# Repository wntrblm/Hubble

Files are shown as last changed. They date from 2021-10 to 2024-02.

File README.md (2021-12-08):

# Hubble

Hubble is Winterbloom's re-usable development board for test jigs.

## Repository layout

This repository contains the hardware design files and firmware files for Hubble.

- **firmware/** contains the firmware source code, build scripts, and third-party dependencies. The firmware is written in C using GCC ARM.
- **hardware/** contains the hardware design files for the mainboard, jackboard, panel, and programming board. These are all created using KiCAD.
- **mechanical/** contains various designs for laser-cut and 3d-printed parts used to modify the stock test jig assembly for Hubble.

## License and contributing

Hubble is open-source hardware and software, however, licensing a project like this is a little complicated. Please take a chance to review the [LICENSE](LICENSE.md) file.

We welcome contributions! Please read our [Contributing Guide](CONTRIBUTING.md) and [Code of Conduct](CODE_OF_CONDUCT.md).

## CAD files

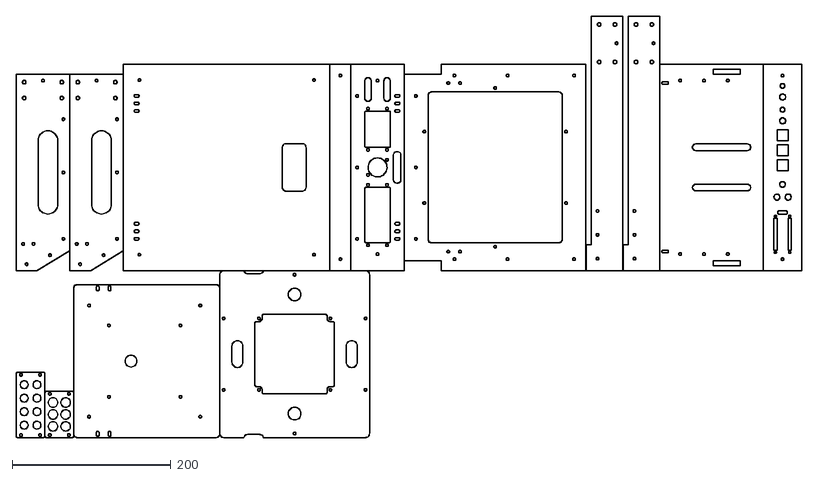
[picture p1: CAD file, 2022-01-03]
mechanical/laser-cuts.dxf
989.4 x 530.3

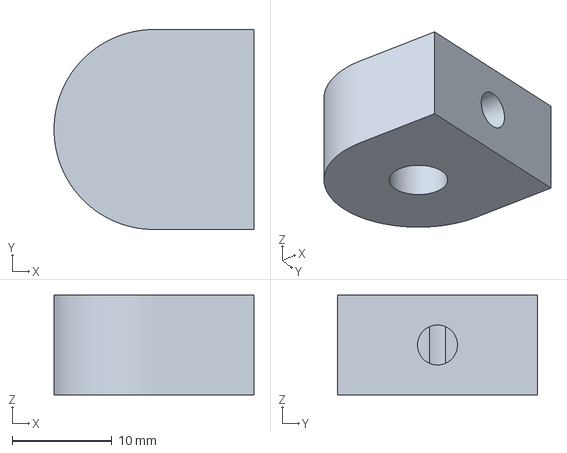
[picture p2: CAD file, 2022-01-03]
mechanical/rail-holder.amf
20.0 x 20.0 x 10.0 mm

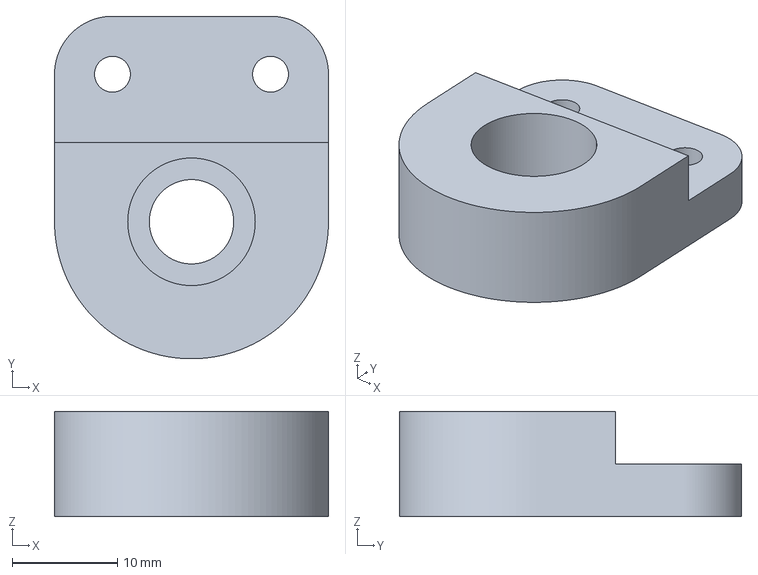
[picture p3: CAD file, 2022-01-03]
mechanical/rail-coupler.amf
26.0 x 32.5 x 10.0 mm

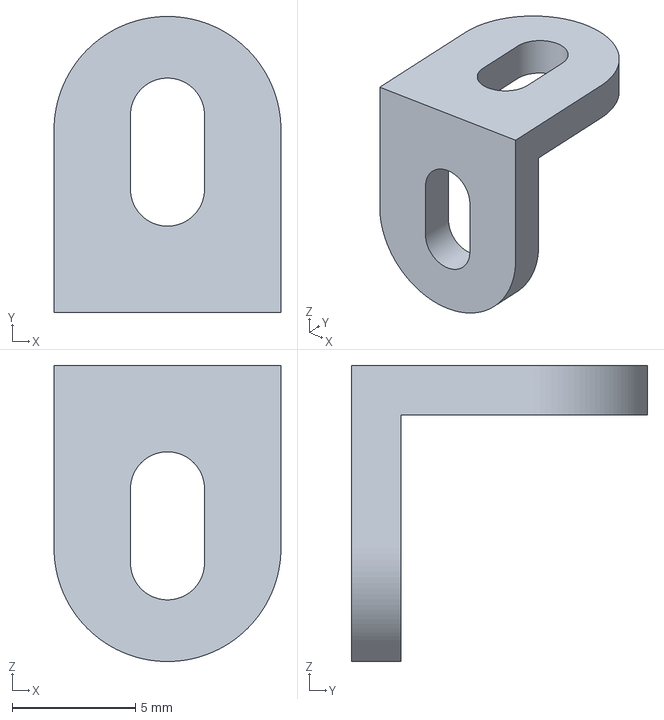
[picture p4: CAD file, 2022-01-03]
mechanical/angle-bracket.amf
9.20 x 12.0 x 12.0 mm

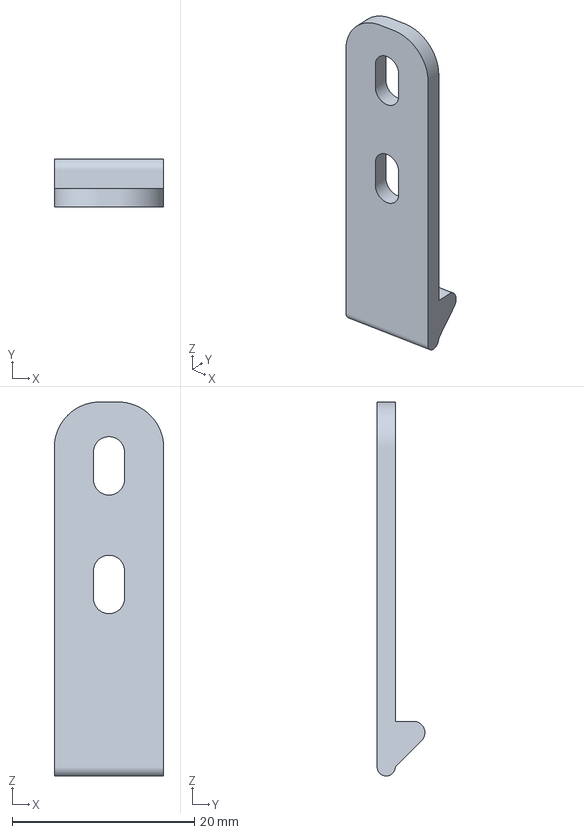
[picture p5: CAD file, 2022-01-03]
mechanical/latch.amf
12.0 x 5.24 x 41.0 mm

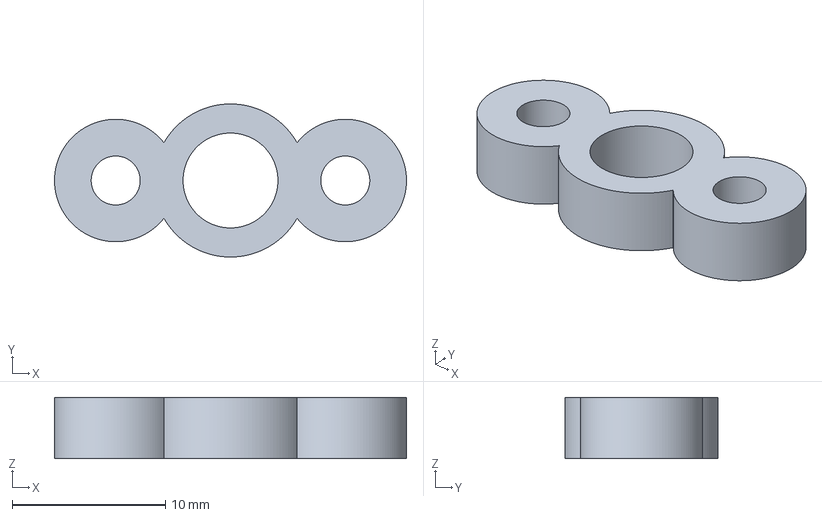
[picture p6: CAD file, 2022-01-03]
mechanical/rail-foot.amf
23.0 x 10.00 x 4.00 mm

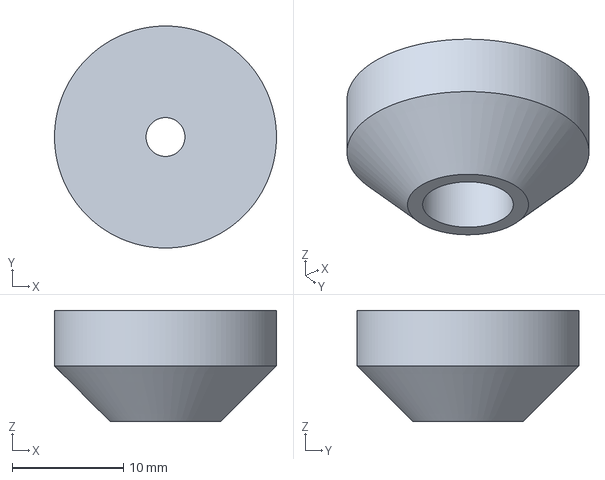
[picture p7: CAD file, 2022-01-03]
mechanical/foot.amf
20.0 x 20.0 x 10.0 mm

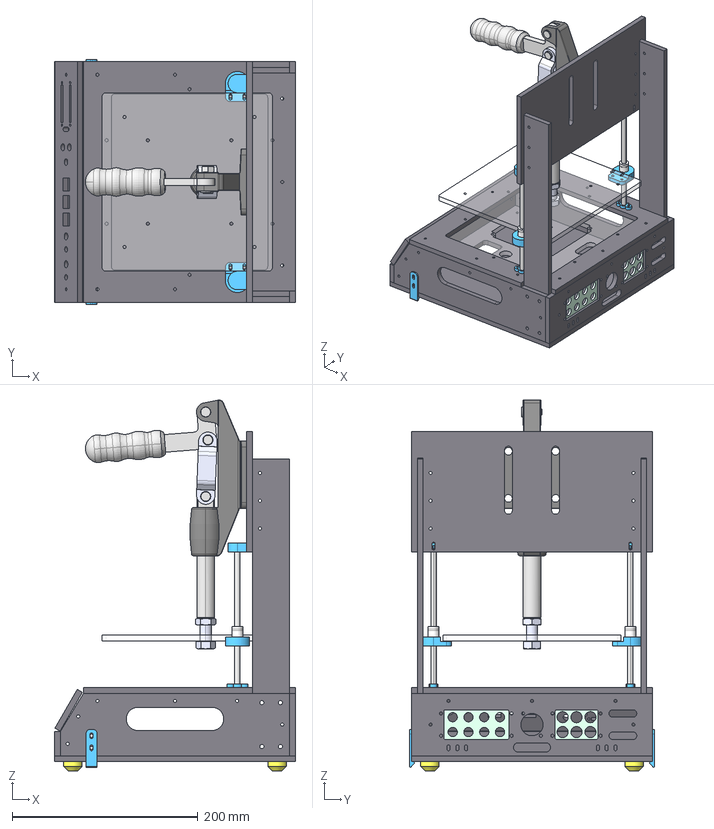
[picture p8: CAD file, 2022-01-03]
mechanical/hubble.FCStd
260.0 x 264.0 x 400.0 mm
6mm x 150mm shaft 5033N123
RailHolder1
RailHolder2
6mm x 150mm shaft 5033N124
RailCoupler1
RailCoupler2
LM6UU1
LM6UU2
RailFoot2
RailFoot1
BoxSide1
BoxSide2
BoxBottom
BoxFront
BoxBack
BoxTop
Arm1
Arm2
ClampPlate
FrontPanel
Foot1
Foot3
Foot4
Foot2
Latch1
Latch2
AngleBracket
Group1^GH-305-HM(²¤ĩ-1
2304HM13-1^GH-305-HM(²¤ĩ-1
Group8^GH-305-HM(²¤ĩ-1
Group5^GH-305-HM(²¤ĩ-1
Group9^GH-305-HM(²¤ĩ-1
LargeIOPlate
SmallIOPlate
PressurePlate
LowerMountingPlate

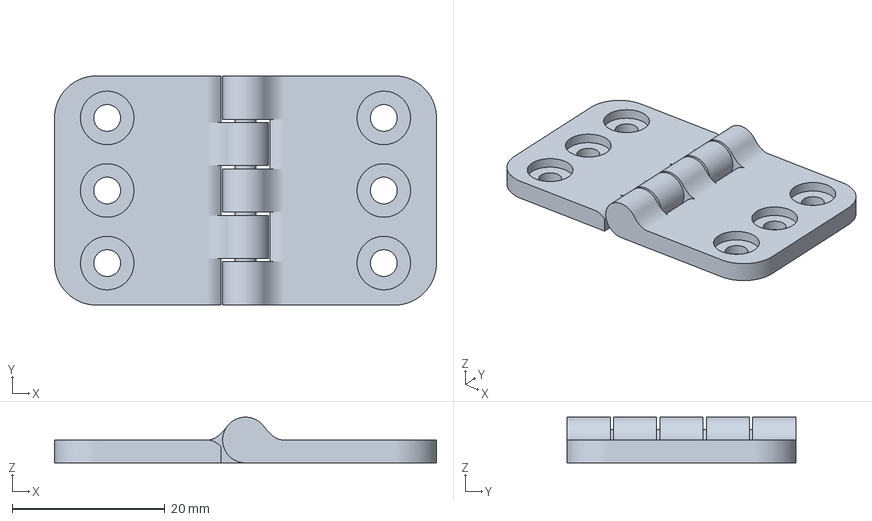
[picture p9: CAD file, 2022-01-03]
mechanical/hinge.3mf
50.0 x 30.0 x 6.00 mm

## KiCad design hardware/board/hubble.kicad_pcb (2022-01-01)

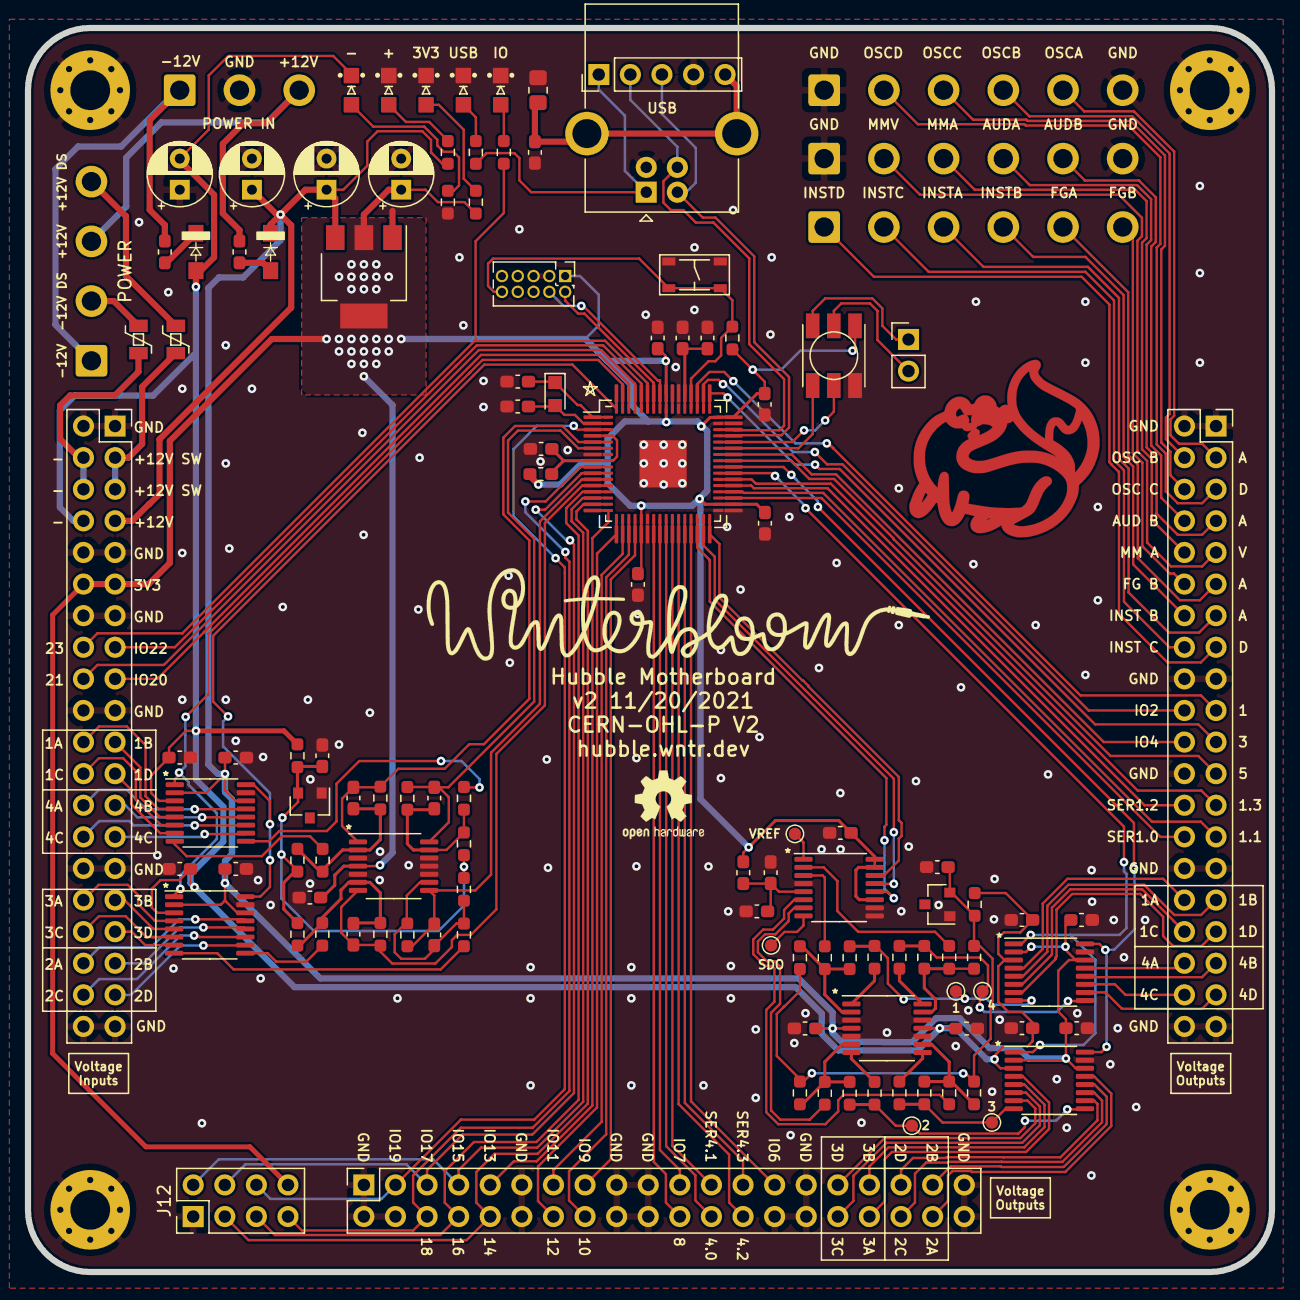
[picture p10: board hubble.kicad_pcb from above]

Board: 2 copper layers, 100.0 x 100.0 mm, 121 parts (0 on the bottom side), 149 nets.

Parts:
C1, C2: 47uF; CP_Radial_D5.0mm_P2.50mm
C3, C4: 10uF; CP_Radial_D5.0mm_P2.50mm
C5: 4.7nF; C_0603_1608Metric_Pad1.08x0.95mm_HandSolder
C6, C9, C11, C12, C13, C14, C15, C16, C17, C19, C20, C25, C26, C27, C28, C29, C30, C31, C32, C33, C34: 0.1uF; C_0603_1608Metric_Pad1.08x0.95mm_HandSolder
C7, C8, C21, C22, C23, C24: 22pF; C_0603_1608Metric_Pad1.08x0.95mm_HandSolder
C10: 4.7uF; C_0603_1608Metric_Pad1.08x0.95mm_HandSolder
C18: 1uF; C_0603_1608Metric_Pad1.08x0.95mm_HandSolder
D1, D2: BARRIER; DIODE_SOD-123_SOD-123F
D3: Dotstar; Dotstar_5050
D4: 3.3; LED_0805_Kingbright_APT2012
D5: +12V; LED_0805_Kingbright_APT2012
D6: -12V; LED_0805_Kingbright_APT2012
D7: ACT; LED_0805_Kingbright_APT2012
D8: VBUS; LED_0805_Kingbright_APT2012
F1, F2: 1A Polyfuse; Littelfuse_0805L
FB1, FB2: 1A; L_0603_1608Metric_Pad1.05x0.95mm_HandSolder
FB3, FB4: 300mA; L_0603_1608Metric_Pad1.05x0.95mm_HandSolder
H1, H2, H3, H4: M3; MountingHole_3.2mm_M3_Pad_Via
J1: POWER; SolderWire-0.75sqmm_1x03_P4.8mm_D1.25mm_OD2.3mm
J2: SWD; PinHeader_2x05_P1.27mm_Vertical
J3: USB B; USB_B_OST_USB-B1HSxx_Horizontal
J4, J8, J9: EXT; SolderWire-0.75sqmm_1x06_P4.8mm_D1.25mm_OD2.3mm
J5: Left; PinSocket_2x20_P2.54mm_Vertical
J6: Right; PinSocket_2x20_P2.54mm_Vertical
J7: Bottom; PinSocket_2x20_P2.54mm_Vertical
J10: Dotstars; PinHeader_1x02_P2.54mm_Vertical
J11: USB; PinHeader_1x05_P2.54mm_Vertical
J12: FRONT; PinHeader_2x04_P2.54mm_Vertical
R1, R2, R3, R4, R6, R15, R16, R17, R18, R35: 10k; R_0603_1608Metric_Pad0.98x0.95mm_HandSolder
R5: 1M; R_0805_2012Metric_Pad1.20x1.40mm_HandSolder
R7, R9, R11, R13: 1.54k; R_0603_1608Metric_Pad0.98x0.95mm_HandSolder
R8, R10, R12, R14: 12.4k; R_0603_1608Metric_Pad0.98x0.95mm_HandSolder
R19, R20, R21, R22, R37: 1k; R_0603_1608Metric_Pad0.98x0.95mm_HandSolder
R23, R25, R27, R29: 100k; R_0603_1608Metric_Pad0.98x0.95mm_HandSolder
R24, R26, R28, R30: 121k; R_0603_1608Metric_Pad0.98x0.95mm_HandSolder
R31, R32, R33, R34: 18.7k; R_0603_1608Metric_Pad0.98x0.95mm_HandSolder
R36: 270; R_0603_1608Metric_Pad0.98x0.95mm_HandSolder
SW1: POWER; SolderWire-0.75sqmm_1x04_P4.8mm_D1.25mm_OD2.3mm
SW2: Reset; Tactile_Switch_4.2mm
TP1: SDO; TestPoint_Pad_D1.0mm
TP2: VREF; TestPoint_Pad_D1.0mm
TP3: 1; TestPoint_Pad_D1.0mm
TP4: 2; TestPoint_Pad_D1.0mm
TP5: 3; TestPoint_Pad_D1.0mm
TP6: 4; TestPoint_Pad_D1.0mm
U1: LD1117-3.3; SOT-223-3_TabPin2
U2, U3: LM4040-10; SOT-23
U4, U7, U8, U9: MUX509; TSSOP-16_4.4x5mm_P0.65mm
U5: ATSAMD51J20A-M; QFN+QFP-64-SAMD51
U6: AD5689R?RUZ; TSSOP-16_4.4x5mm_P0.65mm
U10: OPA4197; TSSOP-14_4.4x5mm_P0.65mm
U11: MCP6004; TSSOP-14_4.4x5mm_P0.65mm
Y1: 32.768 kHz; Crystal_SMD_2012-2Pin_2.0x1.2mm_HandSoldering

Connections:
+3V3: C4.1, C11.1, C12.1, C13.1, C14.1, C16.1, C20.1, D3.4, FB3.2, FB4.2, J2.1, J5.11, J5.12, J12.8, R1.1, R4.2, U1.2, U5.21, U5.34, U5.48, U5.56, U6.11, U6.15, U6.16, U11.4
+12V: C1.1, C3.1, C29.1, C30.1, C31.1, C32.1, C34.1, D2.1, J5.7, R2.1, U1.3, U4.2, U4.14, U7.2, U7.14, U8.2, U8.14, U9.2, U9.14, U10.4
+12VDOWNSTREAM: F1.1, J5.3, J5.5
+12VRAW: FB1.1, J1.3, SW1.3
-12V: C2.2, C25.1, C26.1, C27.1, C28.1, C33.2, D1.2, D6.1, J5.8, R36.1, R37.1, U4.3, U7.3, U8.3, U9.3, U10.11
-12VDOWNSTREAM: F2.2, J5.4, J5.6
-12VRAW: FB2.1, J1.1, SW1.1
/ADC_1A: J5.22, U7.4
/ADC_1B: J5.21, U7.5
/ADC_1C: J5.24, U7.6
/ADC_1D: J5.23, U7.7
/ADC_2A: J5.36, U8.13
/ADC_2B: J5.35, U8.12
/ADC_2C: J5.38, U8.11
/ADC_2D: J5.37, U8.10
/ADC_3A: J5.32, U8.4
/ADC_3B: J5.31, U8.5
/ADC_3C: J5.34, U8.6
/ADC_3D: J5.33, U8.7
/ADC_4A: J5.26, U7.13
/ADC_4B: J5.25, U7.12
/ADC_4C: J5.28, U7.11
/ADC_4D: J5.27, U7.10
/AnalogInBuffers/-10v_ADC: C19.2, R24.2, R26.2, R28.2, R30.2, R37.2, U3.2
/AnalogOutBuffers/-10v_DAC: C15.2, R8.2, R10.2, R12.2, R14.2, R36.2, U2.2
/DAC/DAC_1: R7.2, U6.3
/DAC/DAC_2: R9.2, U6.7
/DAC/DAC_3: R11.2, U6.6
/DAC/DAC_4: R13.2, U6.2
/DAC/SPI_COPI: U5.32, U6.14
/DAC/VDD_DAC: C17.1, C18.1, FB4.1, U6.5
/DAC_1A: J6.32, U9.4
/DAC_1B: J6.31, U9.5
/DAC_1C: J6.34, U9.6
/DAC_1D: J6.33, U9.7
/DAC_2A: J7.38, U4.13
/DAC_2B: J7.37, U4.12
/DAC_2C: J7.36, U4.11
/DAC_2D: J7.35, U4.10
/DAC_3A: J7.34, U4.4
/DAC_3B: J7.33, U4.5
/DAC_3C: J7.32, U4.6
/DAC_3D: J7.31, U4.7
/DAC_4A: J6.36, U9.13
/DAC_4B: J6.35, U9.12
/DAC_4C: J6.38, U9.11
/DAC_4D: J6.37, U9.10
/EXT_AUDIO_A: J4.4, J6.7
/EXT_AUDIO_B: J4.5, J6.8
/EXT_FG_A: J6.11, J9.5
/EXT_FG_B: J6.12, J9.6
/EXT_INST_A: J6.13, J9.3
/EXT_INST_B: J6.14, J9.4
/EXT_INST_C: J6.16, J9.2
/EXT_INST_D: J6.15, J9.1
/EXT_MM_A: J4.3, J6.10
/EXT_MM_V: J4.2, J6.9
/EXT_OSC_A: J6.3, J8.5
/EXT_OSC_B: J6.4, J8.4
/EXT_OSC_C: J6.6, J8.3
/EXT_OSC_D: J6.5, J8.2
/IO1: J6.19, U5.51
/IO2: J6.20, U5.50
/IO3: J6.21, U5.49
/IO4: J6.22, U5.42
/IO5: J6.23, U5.41
/IO6: J7.27, U5.29
/IO7: J7.21, U5.24
/IO8: J7.22, U5.23
/IO9: J7.15, U5.20
/IO10: J7.16, U5.19
/IO11: J7.13, U5.18
/IO12: J7.14, U5.17
/IO13: J7.9, U5.16
/IO14: J7.10, J12.3, U5.15
/IO15: J7.7, J12.2, U5.14
/IO16: J7.8, J12.5, U5.13
/IO17: J7.5, J12.4, U5.10
/IO18: J7.6, J12.7, U5.9
/IO19: J7.3, J12.6, U5.3
/IO20: J5.17, U5.62
/IO21: J5.18, U5.61
/IO22: J5.15, U5.60
/IO23: J5.16, R6.1, U5.59
/MCU/A1: C21.2, R31.1, U5.5, U11.1
/MCU/A2: C22.2, R32.1, U5.12, U11.7
/MCU/A3: C23.2, R33.1, U5.11, U11.8
/MCU/A4: C24.2, R34.1, U5.6, U11.14
/MCU/ADC0.AIN1+ANAREF.VREF0: C6.1, FB3.1, U5.4, U5.8
/MCU/D+: J3.3, J11.2, U5.46
/MCU/D-: J3.2, J11.3, U5.45
/MCU/DAC_CS: U5.31, U6.13
/MCU/DOTSTAR_CI: D3.2, U5.44
/MCU/DOTSTAR_DI: D3.1, U5.43
/MCU/RESET: J2.10, R4.1, SW2.1, U5.52
/MCU/SPI_SCK: U5.30, U6.12
/MCU/SWCLK: J2.4, U5.57
/MCU/SWDIO: J2.2, U5.58
/MCU/VBUS: J3.1, J11.1, R35.1
/MCU/VDDCORE: C9.1, C10.1, U5.53
/MCU/XIN: C7.2, U5.1, Y1.1
/MCU/XOUT: C8.2, U5.2, Y1.2
/Switching/ADC_1: R23.2, U7.8
/Switching/ADC_2: R25.2, U8.9
/Switching/ADC_3: R27.2, U8.8
/Switching/ADC_4: R29.2, U7.9
/Switching/ADC_A0: U5.63, U7.1, U8.1
/Switching/ADC_A1: U5.64, U7.16, U8.16
/Switching/DAC_1: R15.1, R19.1, TP3.1, U9.8
/Switching/DAC_2: R16.1, R20.1, TP4.1, U4.9
/Switching/DAC_3: R17.1, R21.1, TP5.1, U4.8
/Switching/DAC_4: R18.1, R22.1, TP6.1, U9.9
/Switching/DAC_A0: U4.1, U5.39, U9.1
/Switching/DAC_A1: U4.16, U5.40, U9.16
GND: C1.2, C2.1, C3.2, C4.2, C5.2, C6.2, C7.1, C8.1, C9.2, C10.2, C11.2, C12.2, C13.2, C14.2, C15.1, C16.2, C17.2, C18.2, C19.1, C20.2, C25.2, C26.2, C27.2, C28.2, C29.2, C30.2, C31.2, C32.2, C33.1, C34.2, D3.3, D4.1, D5.1, D7.1, D8.1, H1.1, H2.1, H3.1, H4.1, J1.2, J2.3, J2.5, J2.9, J3.4, J4.1, J4.6, J5.1, J5.2, J5.9, J5.10, J5.13, J5.14, J5.19, J5.20, J5.29, J5.30, J5.39, J5.40, J6.1, J6.2, J6.17, J6.18, J6.24, J6.29, J6.30, J6.39, J6.40, J7.1, J7.2, J7.4, J7.11, J7.12, J7.17, J7.18, J7.19, J7.20, J7.28, J7.29, J7.30, J7.39, J7.40, J8.1, J8.6, J11.4, J12.1, R3.1, R5.2, SW2.2, U1.1, U2.1, U3.1, U4.15, U5.7, U5.22, U5.33, U5.47, U5.54, U5.65, U6.4, U6.9, U6.10, U7.15, U8.15, U9.15, U10.3, U10.5, U10.10, U10.12, U11.3, U11.5, U11.10, U11.11, U11.12
unnamed: C5.1, J3.5, J11.5, R5.1
unnamed: C21.1, R23.1, R24.1, R31.2, U11.2
unnamed: C22.1, R25.1, R26.1, R32.2, U11.6
unnamed: C23.1, R27.1, R28.1, R33.2, U11.9
unnamed: C24.1, R29.1, R30.1, R34.2, U11.13
unnamed: D1.1, FB2.2
unnamed: D2.2, FB1.2
unnamed: D3.5, J10.2
unnamed: D3.6, J10.1
unnamed: D4.2, R1.2
unnamed: D5.2, R2.2
unnamed: D6.2, R3.2
unnamed: D7.2, R6.2
unnamed: D8.2, R35.2
unnamed: F1.2, SW1.4
unnamed: F2.1, SW1.2
unnamed: R9.1, R10.1, R16.2, U10.6
unnamed: R11.1, R12.1, R17.2, U10.9
unnamed: R13.1, R14.1, R18.2, U10.13
unnamed: R7.1, R8.1, R15.2, U10.2
unnamed: R19.2, U10.1
unnamed: R20.2, U10.7
unnamed: R21.2, U10.8
unnamed: R22.2, U10.14
unnamed: TP1.1, U6.8
unnamed: TP2.1, U6.1
SERIAL1.0: J6.28, U5.35
SERIAL1.1: J6.27, U5.36
SERIAL1.2: J6.26, U5.37
SERIAL1.3: J6.25, U5.38
SERIAL4.0: J7.24, U5.25
SERIAL4.1: J7.23, U5.26
SERIAL4.2: J7.26, U5.27
SERIAL4.3: J7.25, U5.28

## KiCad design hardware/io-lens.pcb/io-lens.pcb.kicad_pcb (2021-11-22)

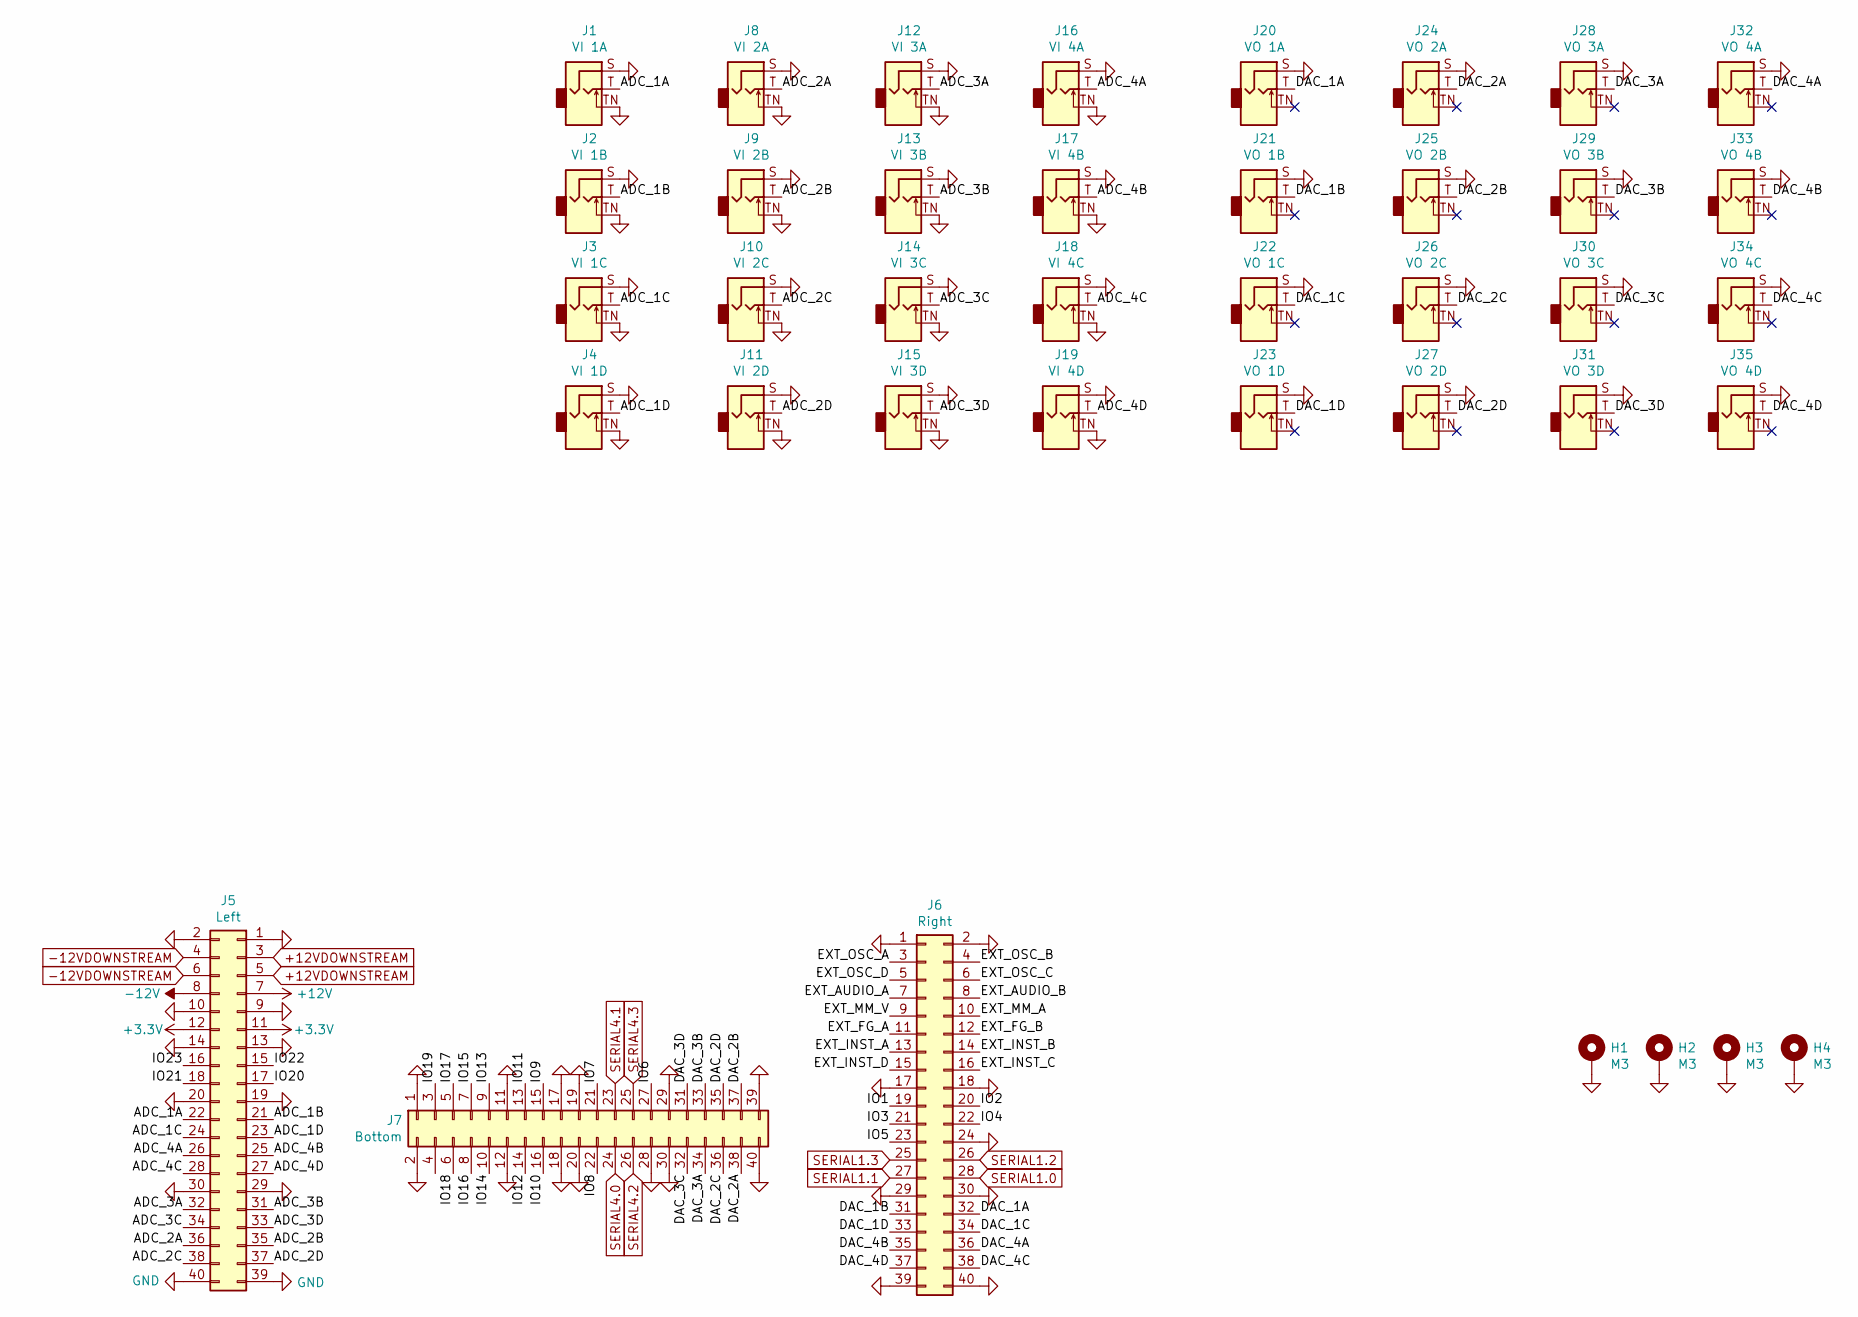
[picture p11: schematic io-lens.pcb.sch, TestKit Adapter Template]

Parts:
H1, H2, H3, H4: M3; MountingHole_3.2mm_M3_Pad_Via
J1: VI 1A; WQP-WQP518MA; mpn WQP-WQP518MA
J2: VI 1B; WQP-WQP518MA; mpn WQP-WQP518MA
J3: VI 1C; WQP-WQP518MA; mpn WQP-WQP518MA
J4: VI 1D; WQP-WQP518MA; mpn WQP-WQP518MA
J5: Left; PinSocket_2x20_P2.54mm_Vertical
J6: Right; PinSocket_2x20_P2.54mm_Vertical
J7: Bottom; PinSocket_2x20_P2.54mm_Vertical
J8: VI 2A; WQP-WQP518MA; mpn WQP-WQP518MA
J9: VI 2B; WQP-WQP518MA; mpn WQP-WQP518MA
J10: VI 2C; WQP-WQP518MA; mpn WQP-WQP518MA
J11: VI 2D; WQP-WQP518MA; mpn WQP-WQP518MA
J12: VI 3A; WQP-WQP518MA; mpn WQP-WQP518MA
J13: VI 3B; WQP-WQP518MA; mpn WQP-WQP518MA
J14: VI 3C; WQP-WQP518MA; mpn WQP-WQP518MA
J15: VI 3D; WQP-WQP518MA; mpn WQP-WQP518MA
J16: VI 4A; WQP-WQP518MA; mpn WQP-WQP518MA
J17: VI 4B; WQP-WQP518MA; mpn WQP-WQP518MA
J18: VI 4C; WQP-WQP518MA; mpn WQP-WQP518MA
J19: VI 4D; WQP-WQP518MA; mpn WQP-WQP518MA
J20: VO 1A; WQP-WQP518MA; mpn WQP-WQP518MA
J21: VO 1B; WQP-WQP518MA; mpn WQP-WQP518MA
J22: VO 1C; WQP-WQP518MA; mpn WQP-WQP518MA
J23: VO 1D; WQP-WQP518MA; mpn WQP-WQP518MA
J24: VO 2A; WQP-WQP518MA; mpn WQP-WQP518MA
J25: VO 2B; WQP-WQP518MA; mpn WQP-WQP518MA
J26: VO 2C; WQP-WQP518MA; mpn WQP-WQP518MA
J27: VO 2D; WQP-WQP518MA; mpn WQP-WQP518MA
J28: VO 3A; WQP-WQP518MA; mpn WQP-WQP518MA
J29: VO 3B; WQP-WQP518MA; mpn WQP-WQP518MA
J30: VO 3C; WQP-WQP518MA; mpn WQP-WQP518MA
J31: VO 3D; WQP-WQP518MA; mpn WQP-WQP518MA
J32: VO 4A; WQP-WQP518MA; mpn WQP-WQP518MA
J33: VO 4B; WQP-WQP518MA; mpn WQP-WQP518MA
J34: VO 4C; WQP-WQP518MA; mpn WQP-WQP518MA
J35: VO 4D; WQP-WQP518MA; mpn WQP-WQP518MA

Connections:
+3V3: J5.11, J5.12
+12V: J5.7
+12VDOWNSTREAM: J5.3, J5.5
-12V: J5.8
-12VDOWNSTREAM: J5.4, J5.6
/ADC_1A: J1.T (Tip), J5.22
/ADC_1B: J2.T (Tip), J5.21
/ADC_1C: J3.T (Tip), J5.24
/ADC_1D: J4.T (Tip), J5.23
/ADC_2A: J5.36, J8.T (Tip)
/ADC_2B: J5.35, J9.T (Tip)
/ADC_2C: J5.38, J10.T (Tip)
/ADC_2D: J5.37, J11.T (Tip)
/ADC_3A: J5.32, J12.T (Tip)
/ADC_3B: J5.31, J13.T (Tip)
/ADC_3C: J5.34, J14.T (Tip)
/ADC_3D: J5.33, J15.T (Tip)
/ADC_4A: J5.26, J16.T (Tip)
/ADC_4B: J5.25, J17.T (Tip)
/ADC_4C: J5.28, J18.T (Tip)
/ADC_4D: J5.27, J19.T (Tip)
/DAC_1A: J6.32, J20.T (Tip)
/DAC_1B: J6.31, J21.T (Tip)
/DAC_1C: J6.34, J22.T (Tip)
/DAC_1D: J6.33, J23.T (Tip)
/DAC_2A: J7.38, J24.T (Tip)
/DAC_2B: J7.37, J25.T (Tip)
/DAC_2C: J7.36, J26.T (Tip)
/DAC_2D: J7.35, J27.T (Tip)
/DAC_3A: J7.34, J28.T (Tip)
/DAC_3B: J7.33, J29.T (Tip)
/DAC_3C: J7.32, J30.T (Tip)
/DAC_3D: J7.31, J31.T (Tip)
/DAC_4A: J6.36, J32.T (Tip)
/DAC_4B: J6.35, J33.T (Tip)
/DAC_4C: J6.38, J34.T (Tip)
/DAC_4D: J6.37, J35.T (Tip)
/EXT_AUDIO_A: J6.7
/EXT_AUDIO_B: J6.8
/EXT_FG_A: J6.11
/EXT_FG_B: J6.12
/EXT_INST_A: J6.13
/EXT_INST_B: J6.14
/EXT_INST_C: J6.16
/EXT_INST_D: J6.15
/EXT_MM_A: J6.10
/EXT_MM_V: J6.9
/EXT_OSC_A: J6.3
/EXT_OSC_B: J6.4
/EXT_OSC_C: J6.6
/EXT_OSC_D: J6.5
/IO1: J6.19
/IO2: J6.20
/IO3: J6.21
/IO4: J6.22
/IO5: J6.23
/IO6: J7.27
/IO7: J7.21
/IO8: J7.22
/IO9: J7.15
/IO10: J7.16
/IO11: J7.13
/IO12: J7.14
/IO13: J7.9
/IO14: J7.10
/IO15: J7.7
/IO16: J7.8
/IO17: J7.5
/IO18: J7.6
/IO19: J7.3
/IO20: J5.17
/IO21: J5.18
/IO22: J5.15
/IO23: J5.16
GND: H1.1, H2.1, H3.1, H4.1, J1.S (Sleeve), J1.TN (Tip_normalize), J2.S (Sleeve), J2.TN (Tip_normalize), J3.S (Sleeve), J3.TN (Tip_normalize), J4.S (Sleeve), J4.TN (Tip_normalize), J5.1, J5.2, J5.9, J5.10, J5.13, J5.14, J5.19, J5.20, J5.29, J5.30, J5.39, J5.40, J6.1, J6.2, J6.17, J6.18, J6.24, J6.29, J6.30, J6.39, J6.40, J7.1, J7.2, J7.11, J7.12, J7.17, J7.18, J7.19, J7.20, J7.28, J7.29, J7.30, J7.39, J7.40, J8.S (Sleeve), J8.TN (Tip_normalize), J9.S (Sleeve), J9.TN (Tip_normalize), J10.S (Sleeve), J10.TN (Tip_normalize), J11.S (Sleeve), J11.TN (Tip_normalize), J12.S (Sleeve), J12.TN (Tip_normalize), J13.S (Sleeve), J13.TN (Tip_normalize), J14.S (Sleeve), J14.TN (Tip_normalize), J15.S (Sleeve), J15.TN (Tip_normalize), J16.S (Sleeve), J16.TN (Tip_normalize), J17.S (Sleeve), J17.TN (Tip_normalize), J18.S (Sleeve), J18.TN (Tip_normalize), J19.S (Sleeve), J19.TN (Tip_normalize), J20.S (Sleeve), J21.S (Sleeve), J22.S (Sleeve), J23.S (Sleeve), J24.S (Sleeve), J25.S (Sleeve), J26.S (Sleeve), J27.S (Sleeve), J28.S (Sleeve), J29.S (Sleeve), J30.S (Sleeve), J31.S (Sleeve), J32.S (Sleeve), J33.S (Sleeve), J34.S (Sleeve), J35.S (Sleeve)
SERIAL1.0: J6.28
SERIAL1.1: J6.27
SERIAL1.2: J6.26
SERIAL1.3: J6.25
SERIAL4.0: J7.24
SERIAL4.1: J7.23
SERIAL4.2: J7.26
SERIAL4.3: J7.25

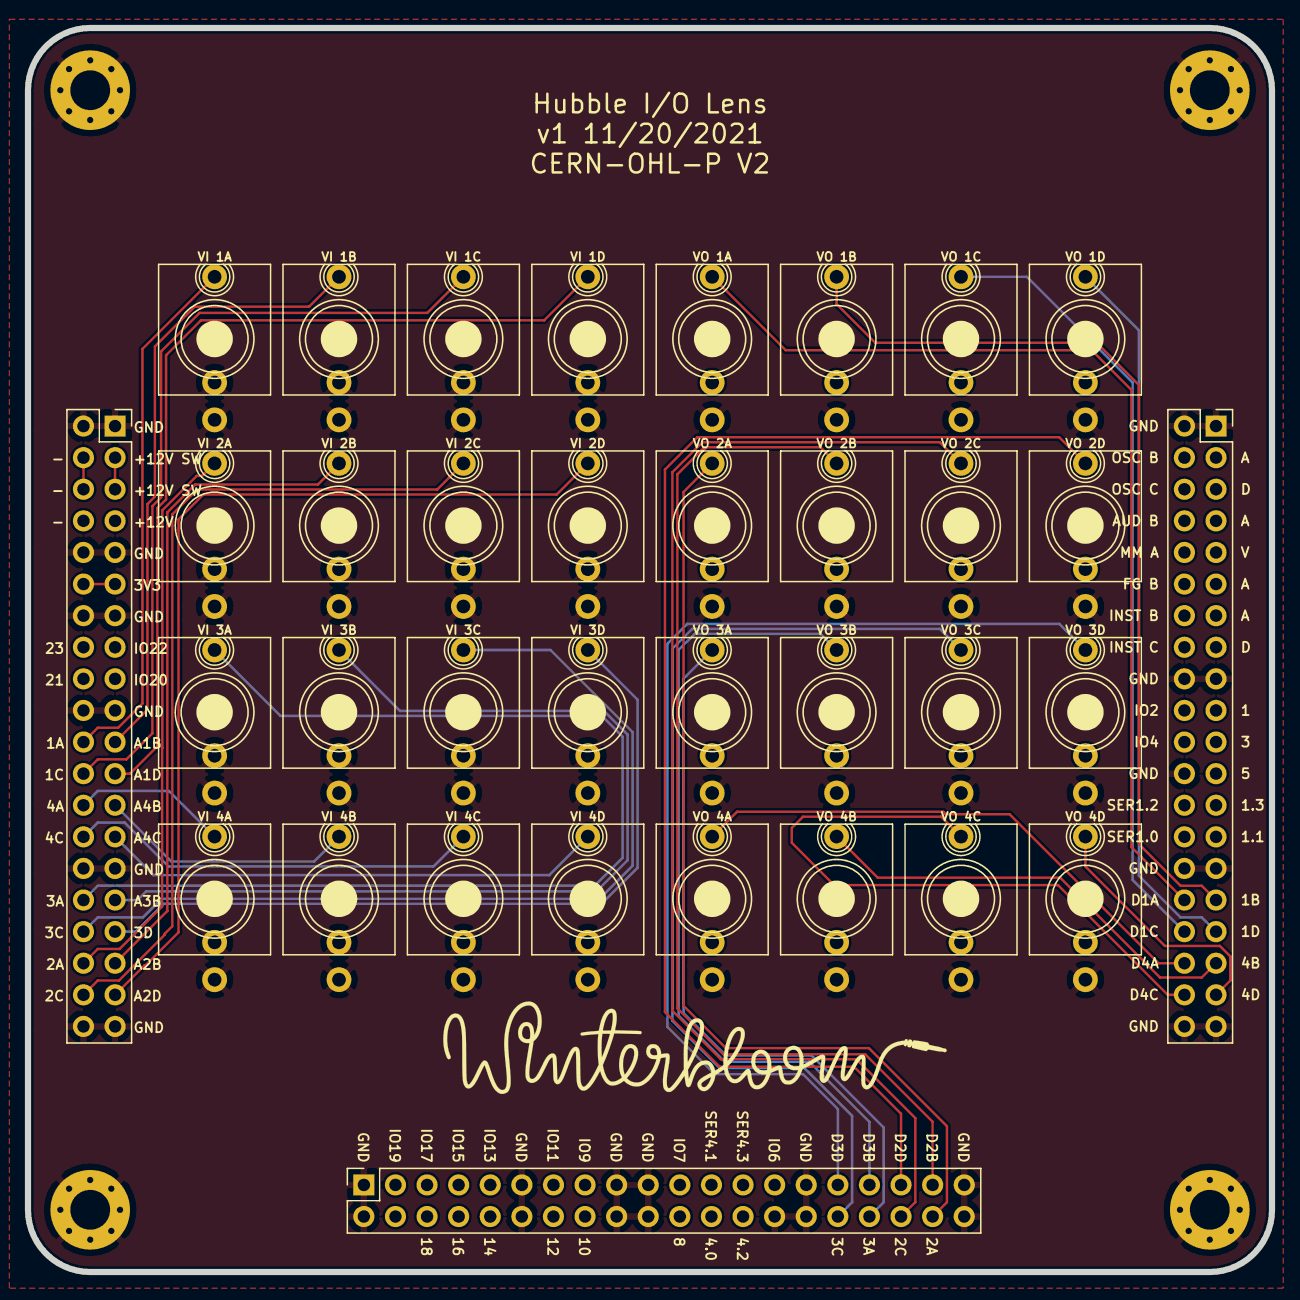
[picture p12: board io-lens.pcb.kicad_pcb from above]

Board: 2 copper layers, 100.0 x 100.0 mm, 39 parts (0 on the bottom side), 36 nets.

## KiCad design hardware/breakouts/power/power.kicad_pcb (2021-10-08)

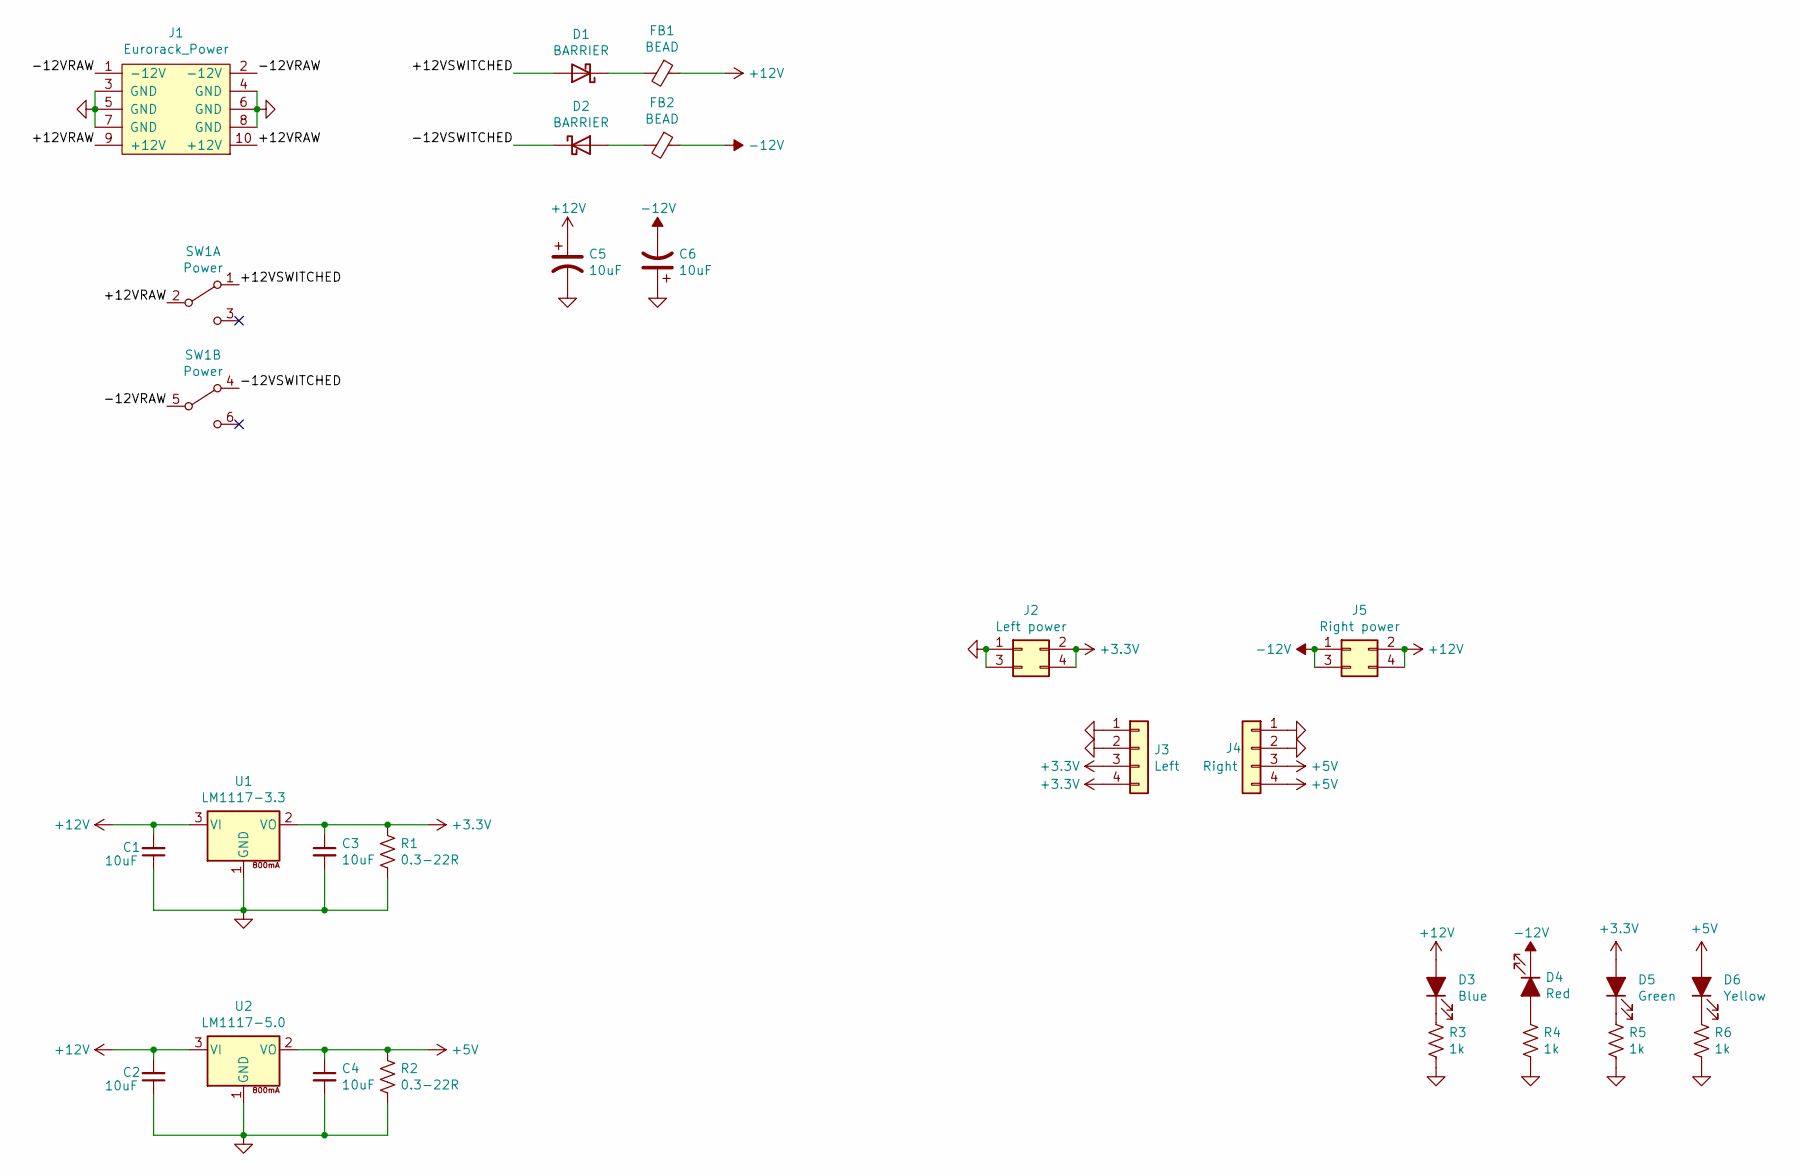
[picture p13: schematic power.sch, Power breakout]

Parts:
C1, C2, C3, C4: 10uF; C_0805_2012Metric_Pad1.18x1.45mm_HandSolder
C5, C6: 10uF; CP_Radial_D5.0mm_P2.50mm
D1, D2: BARRIER; D_SOD-123
D3: Blue; LED_D3.0mm
D4: Red; LED_D3.0mm
D5: Green; LED_D3.0mm
D6: Yellow; LED_D3.0mm
FB1, FB2: BEAD; L_0603_1608Metric_Pad1.05x0.95mm_HandSolder
J1: Eurorack_Power; mpn 302-S101
J2: Left power; PinHeader_2x02_P2.54mm_Vertical
J3: Left; PinHeader_1x04_P2.54mm_Vertical
J4: Right; PinHeader_1x04_P2.54mm_Vertical
J5: Right power; PinHeader_2x02_P2.54mm_Vertical
R1, R2: 0.3-22R; R_0805_2012Metric
R3, R4, R5, R6: 1k; R_0603_1608Metric_Pad0.98x0.95mm_HandSolder
SW1: Power; Switch_DPDT_Thonk_DW4_2.54mm_pitch_5.08mm_spacing
U1: LM1117-3.3; SOT-223-3_TabPin2; mpn LM1117IMP-3.3
U2: LM1117-5.0; SOT-223-3_TabPin2; mpn LM1117IMP-3.3

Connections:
+3V3: C3.1, D5.2 (A), J2.2, J2.4, J3.3, J3.4, R1.1, U1.2 (VO)
+5V: C4.1, D6.2 (A), J4.3, J4.4, R2.1, U2.2 (VO)
+12V: C1.2, C2.2, C5.1, D3.2 (A), FB1.1, J5.2, J5.4, U1.3 (VI), U2.3 (VI)
-12V: C6.2, D4.1 (K), FB2.1, J5.1, J5.3
/+12VRAW: J1.9 (+12V), J1.10 (+12V), SW1.2 (B)
/+12VSWITCHED: D1.2 (A), SW1.1 (A)
/-12VRAW: J1.1 (-12V), J1.2 (-12V), SW1.5 (B)
/-12VSWITCHED: D2.1 (K), SW1.4 (A)
GND: C1.1, C2.1, C3.2, C4.2, C5.2, C6.1, J1.3 (GND), J1.4 (GND), J1.5 (GND), J1.6 (GND), J1.7 (GND), J1.8 (GND), J2.1, J2.3, J3.1, J3.2, J4.1, J4.2, R1.2, R2.2, R3.2, R4.2, R5.2, R6.2, U1.1 (GND), U2.1 (GND)
unnamed: D1.1 (K), FB1.2
unnamed: D2.2 (A), FB2.2
unnamed: D3.1 (K), R3.1
unnamed: D4.2 (A), R4.1
unnamed: D5.1 (K), R5.1
unnamed: D6.1 (K), R6.1

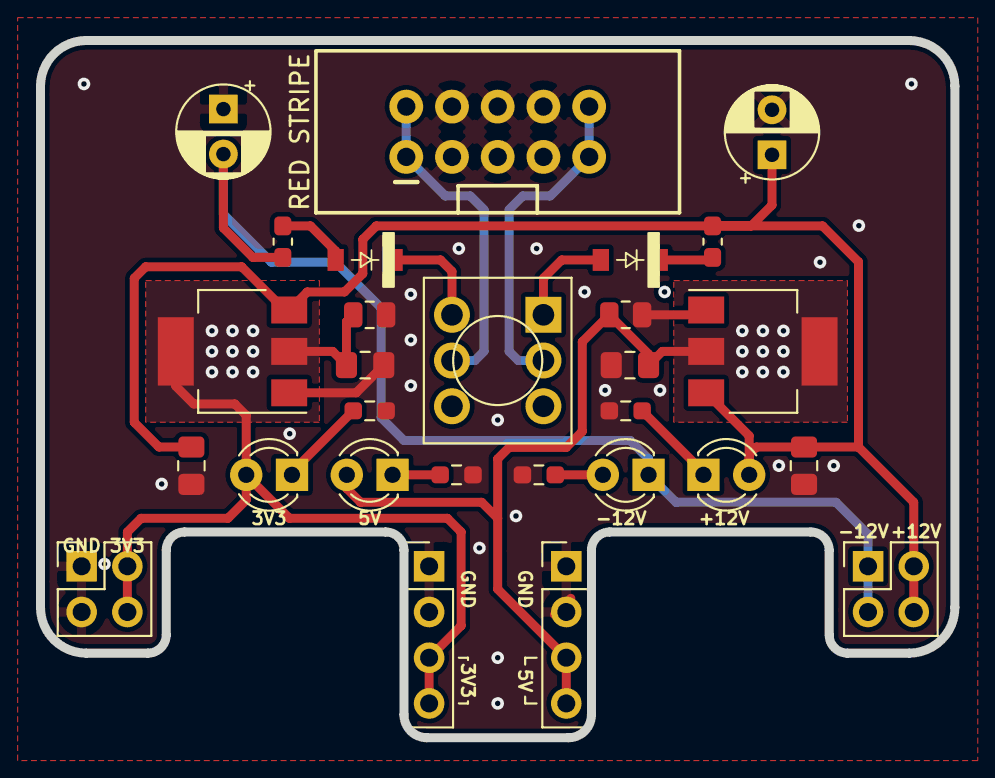
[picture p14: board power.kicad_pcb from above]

Board: 2 copper layers, 50.8 x 38.7 mm, 28 parts (0 on the bottom side), 15 nets.

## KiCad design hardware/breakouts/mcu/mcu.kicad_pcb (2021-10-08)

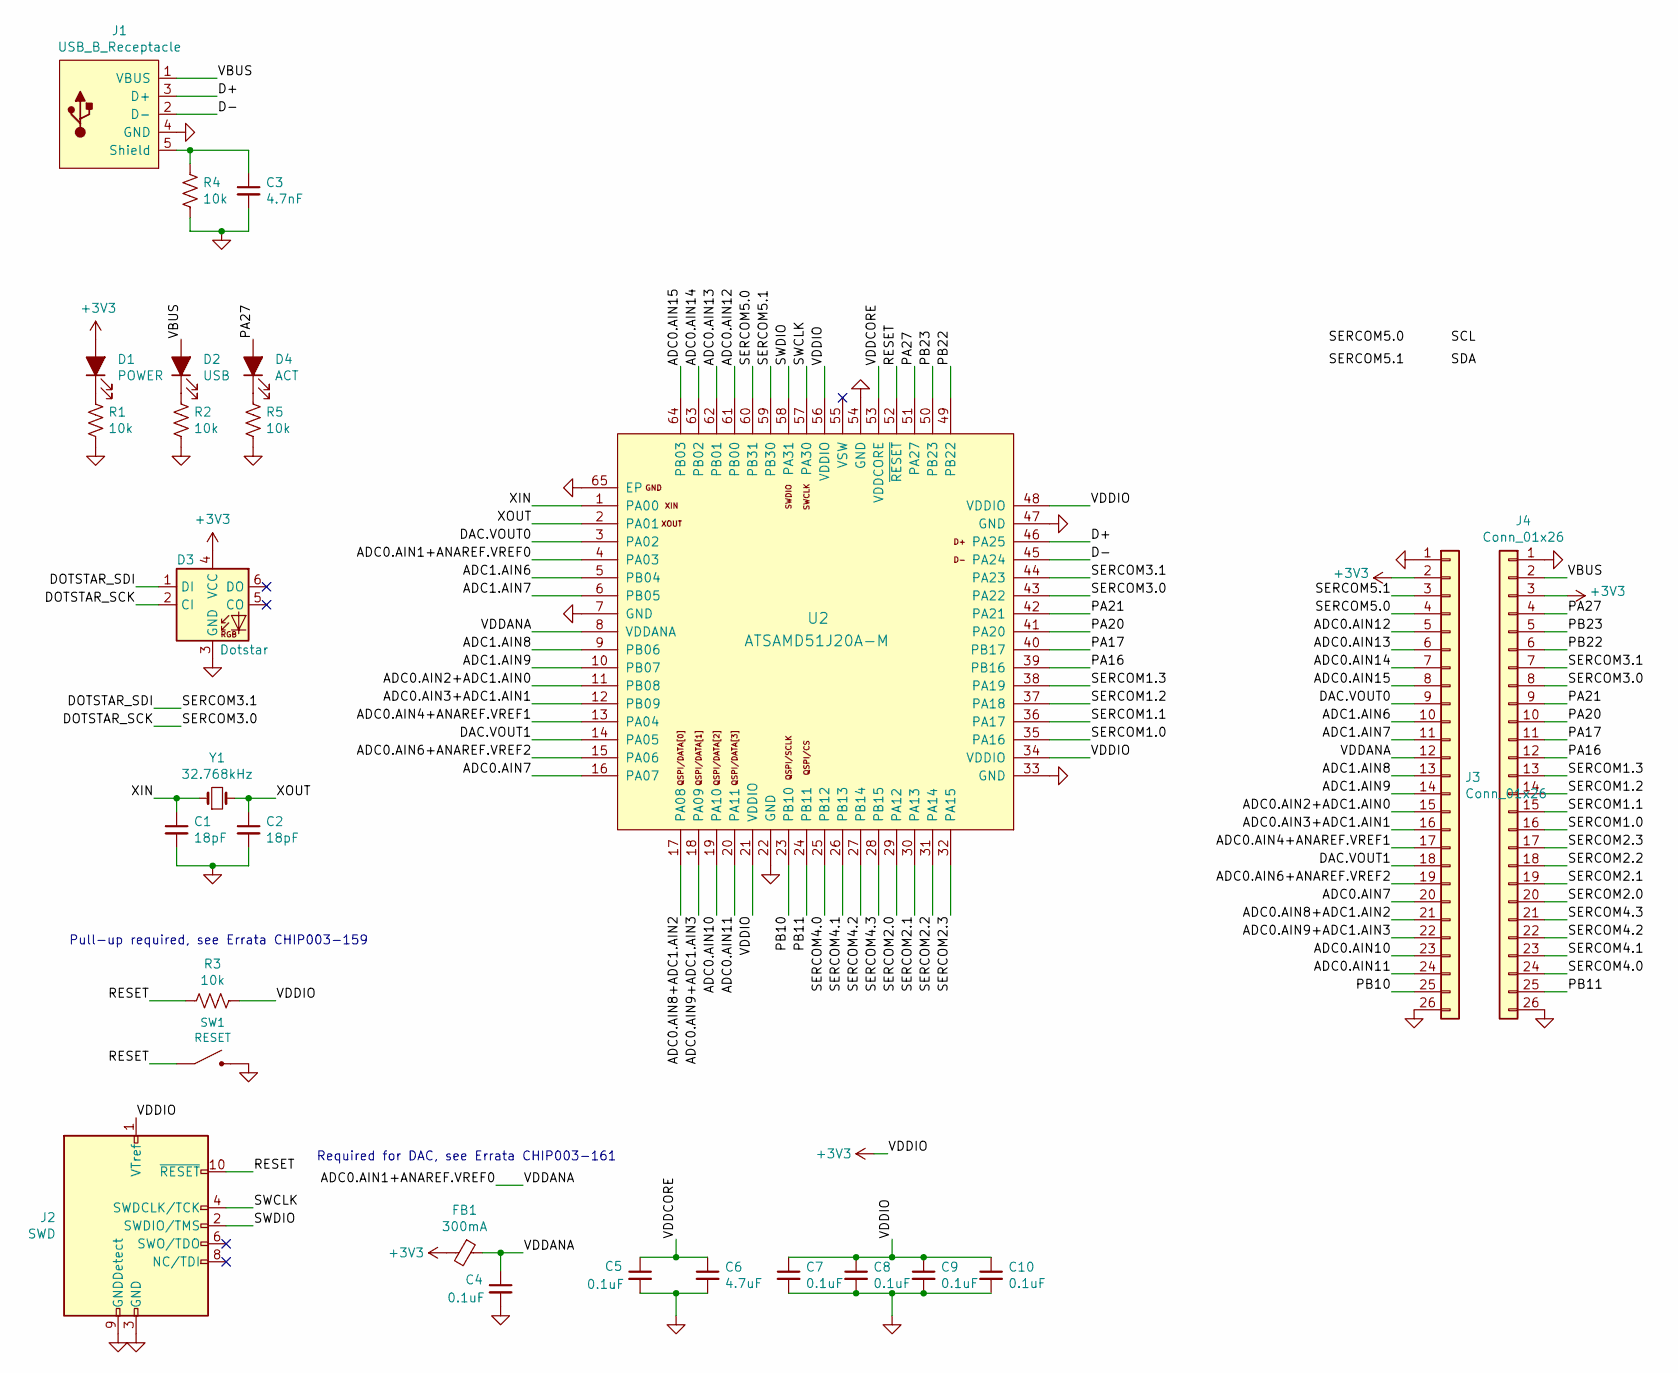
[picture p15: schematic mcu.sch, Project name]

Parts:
C1, C2: 18pF; C_0603_1608Metric_Pad1.08x0.95mm_HandSolder
C3: 4.7nF; C_0603_1608Metric_Pad1.08x0.95mm_HandSolder
C4, C5, C7, C8, C9, C10: 0.1uF; C_0603_1608Metric_Pad1.08x0.95mm_HandSolder
C6: 4.7uF; C_0603_1608Metric_Pad1.08x0.95mm_HandSolder
D1: POWER; LED_0805_Kingbright_APT2012
D2: USB; LED_0805_Kingbright_APT2012
D3: Dotstar; Dotstar_5050; mpn SK9822
D4: ACT; LED_0805_Kingbright_APT2012
FB1: 300mA; L_0603_1608Metric_Pad1.05x0.95mm_HandSolder
J1: USB_B_Receptacle; USB_B_OST_USB-B1HSxx_Horizontal; mpn 5787834-1
J2: SWD; PinHeader_2x05_P1.27mm_Vertical
J3, J4: Conn_01x26; PinSocket_1x26_P2.54mm_Vertical
R1, R2, R3, R4, R5: 10k; R_0603_1608Metric_Pad0.98x0.95mm_HandSolder
SW1: RESET; Tactile_Switch_4.2mm; mpn MF-SW-TACT-4.2MM, MF-SW-TACT-6MM
U2: ATSAMD51J20A-M; QFN-64-1EP_9x9mm_P0.5mm_EP3.8x3.8mm; mpn ATSAMD51J20A-M
Y1: 32.768kHz; Crystal_SMD_2012-2Pin_2.0x1.2mm_HandSoldering

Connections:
+3V3: C7.1, C8.1, C9.1, C10.1, D1.2 (A), D3.4 (VCC), FB1.2, J2.1 (VTref), J3.2, J4.3, R3.1, U2.21 (VDDIO), U2.34 (VDDIO), U2.48 (VDDIO), U2.56 (VDDIO)
/ADC0.AIN1+ANAREF.VREF0: C4.1, FB1.1, J3.12, U2.4 (PA03), U2.8 (VDDANA)
/ADC0.AIN2+ADC1.AIN0: J3.15, U2.11 (PB08)
/ADC0.AIN3+ADC1.AIN1: J3.16, U2.12 (PB09)
/ADC0.AIN4+ANAREF.VREF1: J3.17, U2.13 (PA04)
/ADC0.AIN6+ANAREF.VREF2: J3.19, U2.15 (PA06)
/ADC0.AIN7: J3.20, U2.16 (PA07)
/ADC0.AIN8+ADC1.AIN2: J3.21, U2.17 (PA08)
/ADC0.AIN9+ADC1.AIN3: J3.22, U2.18 (PA09)
/ADC0.AIN10: J3.23, U2.19 (PA10)
/ADC0.AIN11: J3.24, U2.20 (PA11)
/ADC0.AIN12: J3.5, U2.61 (PB00)
/ADC0.AIN13: J3.6, U2.62 (PB01)
/ADC0.AIN14: J3.7, U2.63 (PB02)
/ADC0.AIN15: J3.8, U2.64 (PB03)
/ADC1.AIN6: J3.10, U2.5 (PB04)
/ADC1.AIN7: J3.11, U2.6 (PB05)
/ADC1.AIN8: J3.13, U2.9 (PB06)
/ADC1.AIN9: J3.14, U2.10 (PB07)
/D+: J1.3 (D+), U2.46 (PA25)
/D-: J1.2 (D-), U2.45 (PA24)
/DAC.VOUT0: J3.9, U2.3 (PA02)
/DAC.VOUT1: J3.18, U2.14 (PA05)
/DOTSTAR_SCK: D3.2 (CI), J4.8, U2.43 (PA22)
/DOTSTAR_SDI: D3.1 (DI), J4.7, U2.44 (PA23)
/PA16: J4.12, U2.39 (PB16)
/PA17: J4.11, U2.40 (PB17)
/PA20: J4.10, U2.41 (PA20)
/PA21: J4.9, U2.42 (PA21)
/PA27: D4.2 (A), J4.4, U2.51 (PA27)
/PB10: J3.25, U2.23 (PB10)
/PB11: J4.25, U2.24 (PB11)
/PB22: J4.6, U2.49 (PB22)
/PB23: J4.5, U2.50 (PB23)
/RESET: J2.10 (~RESET~), R3.2, SW1.1, U2.52 (~RESET)
/SERCOM1.0: J4.16, U2.35 (PA16)
/SERCOM1.1: J4.15, U2.36 (PA17)
/SERCOM1.2: J4.14, U2.37 (PA18)
/SERCOM1.3: J4.13, U2.38 (PA19)
/SERCOM2.0: J4.20, U2.29 (PA12)
/SERCOM2.1: J4.19, U2.30 (PA13)
/SERCOM2.2: J4.18, U2.31 (PA14)
/SERCOM2.3: J4.17, U2.32 (PA15)
/SERCOM4.0: J4.24, U2.25 (PB12)
/SERCOM4.1: J4.23, U2.26 (PB13)
/SERCOM4.2: J4.22, U2.27 (PB14)
/SERCOM4.3: J4.21, U2.28 (PB15)
/SERCOM5.0: J3.4, U2.60 (PB31)
/SERCOM5.1: J3.3, U2.59 (PB30)
/SWCLK: J2.4 (SWDCLK/TCK), U2.57 (PA30)
/SWDIO: J2.2 (SWDIO/TMS), U2.58 (PA31)
/VBUS: D2.2 (A), J1.1 (VBUS), J4.2
/VDDCORE: C5.1, C6.1, U2.53 (VDDCORE)
/XIN: C1.1, U2.1 (PA00), Y1.1
/XOUT: C2.1, U2.2 (PA01), Y1.2
GND: C1.2, C2.2, C3.2, C4.2, C5.2, C6.2, C7.2, C8.2, C9.2, C10.2, D3.3 (GND), J1.4 (GND), J2.3 (GND), J2.5 (GND), J2.9 (GNDDetect), J3.1, J3.26, J4.1, J4.26, R1.2, R2.2, R4.2, R5.2, SW1.2, U2.7 (GND), U2.22 (GND), U2.33 (GND), U2.47 (GND), U2.54 (GND), U2.65 (EP)
unnamed: C3.1, J1.5 (Shield), R4.1
unnamed: D1.1 (K), R1.1
unnamed: D2.1 (K), R2.1
unnamed: D4.1 (K), R5.1

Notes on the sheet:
Pull-up required, see Errata CHIP003-159
Required for DAC, see Errata CHIP003-161

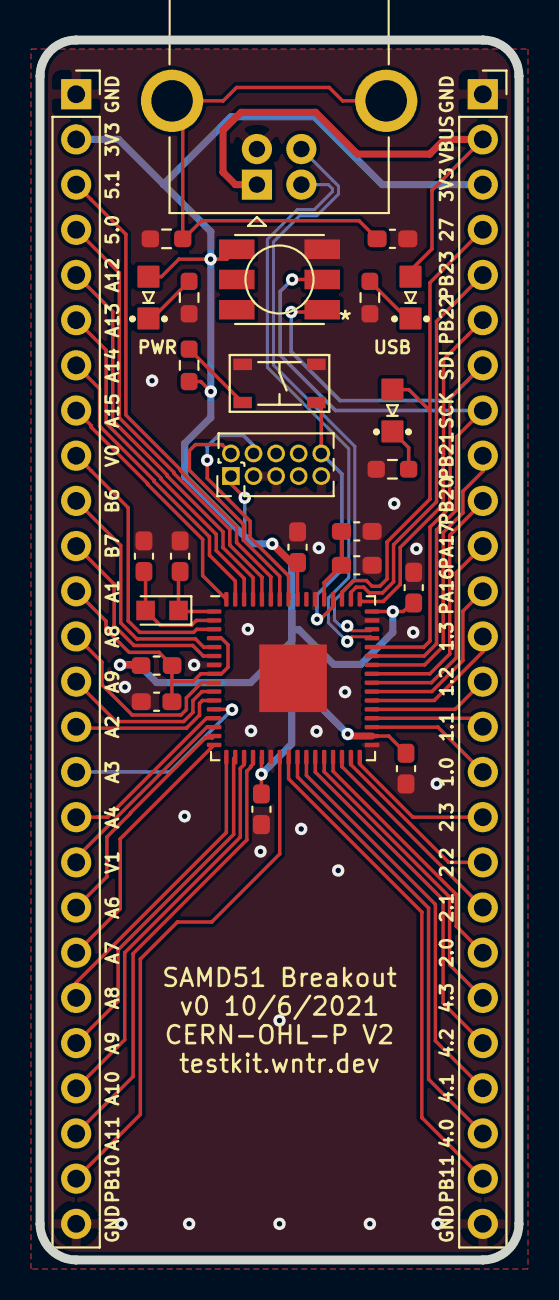
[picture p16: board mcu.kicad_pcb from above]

Board: 2 copper layers, 26.9 x 68.6 mm, 27 parts (0 on the bottom side), 60 nets.

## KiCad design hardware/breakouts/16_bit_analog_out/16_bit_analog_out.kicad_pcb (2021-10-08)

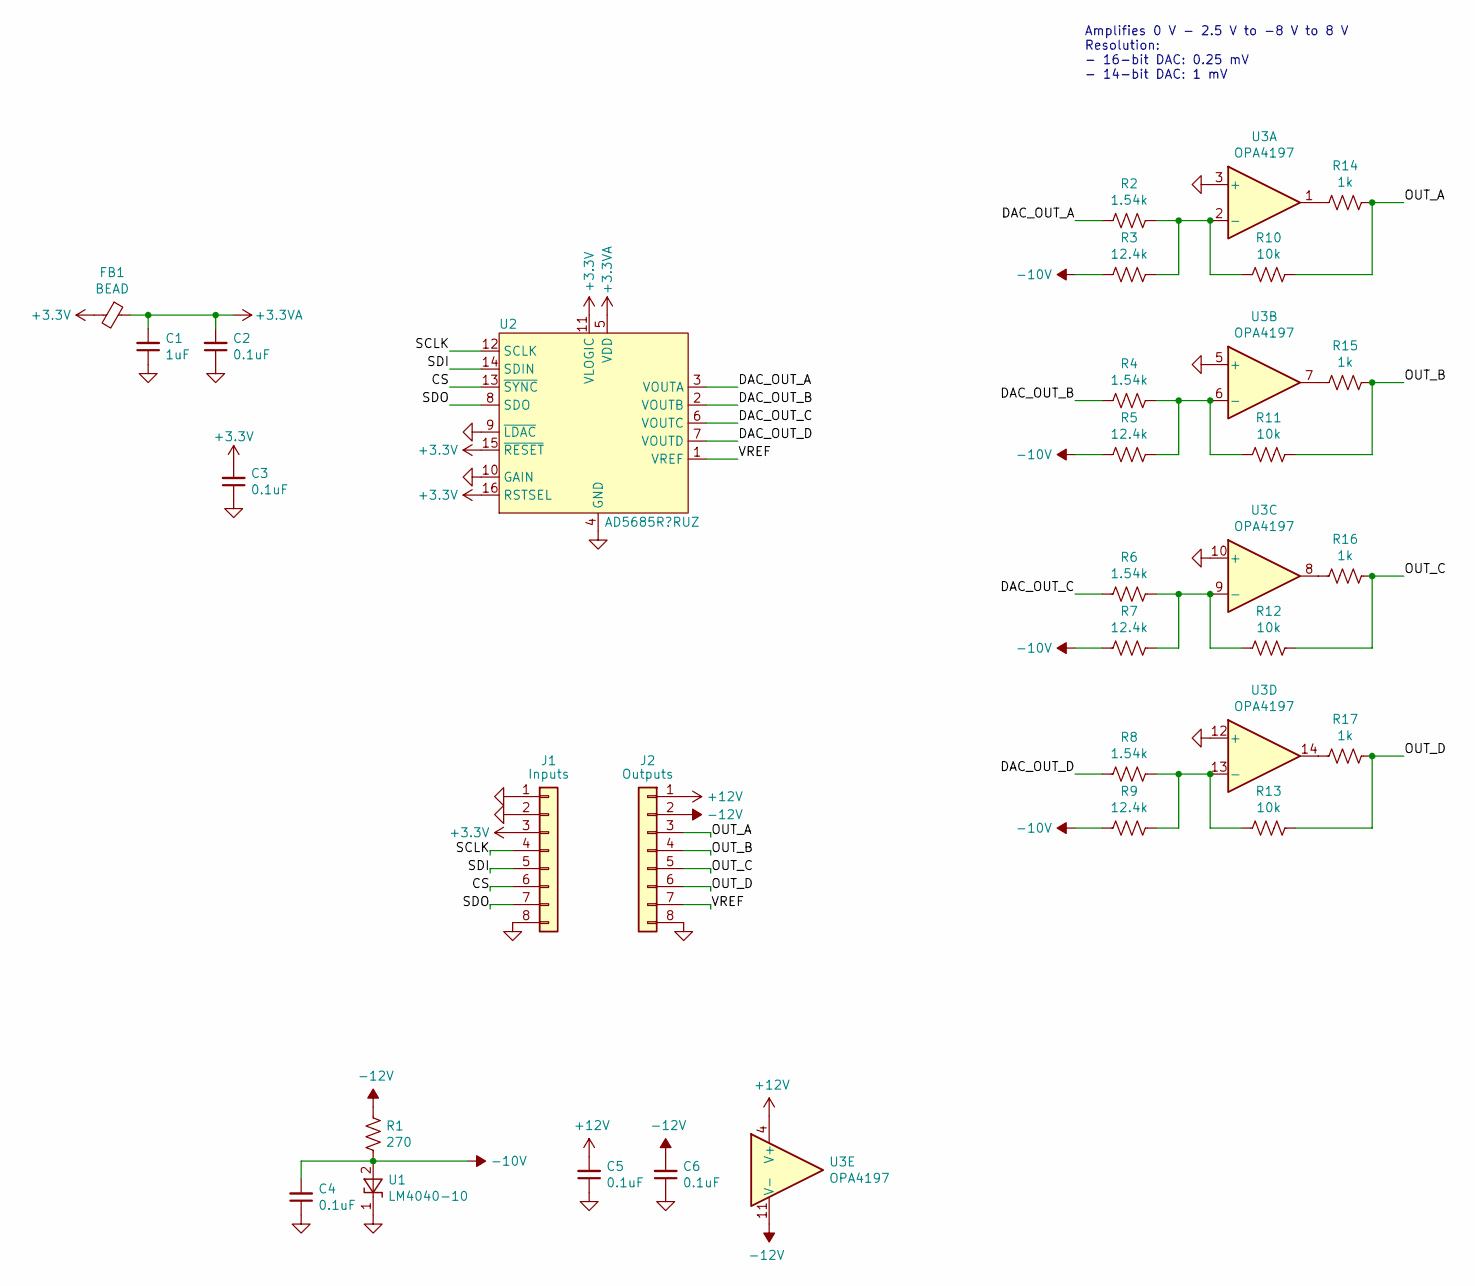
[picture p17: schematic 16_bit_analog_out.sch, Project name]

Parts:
C1: 1uF; C_0603_1608Metric_Pad1.08x0.95mm_HandSolder
C2, C3, C4, C5, C6: 0.1uF; C_0603_1608Metric_Pad1.08x0.95mm_HandSolder
FB1: BEAD; L_0603_1608Metric_Pad1.05x0.95mm_HandSolder
J1: Inputs; PinHeader_1x08_P2.54mm_Vertical
J2: Outputs; PinHeader_1x08_P2.54mm_Vertical
R1: 270; R_0603_1608Metric_Pad0.98x0.95mm_HandSolder
R2, R4, R6, R8: 1.54k; R_0603_1608Metric_Pad0.98x0.95mm_HandSolder
R3, R5, R7, R9: 12.4k; R_0603_1608Metric_Pad0.98x0.95mm_HandSolder
R10, R11, R12, R13: 10k; R_0603_1608Metric_Pad0.98x0.95mm_HandSolder
R14, R15, R16, R17: 1k; R_0603_1608Metric_Pad0.98x0.95mm_HandSolder
U1: LM4040-10; SOT-23; mpn LM4040DIM3-10.0/NOPB
U2: AD5685R?RUZ; TSSOP-16_4.4x5mm_P0.65mm; mpn AD5685ARUZ, AD5685BRUZ
U3: OPA4197; TSSOP-14_4.4x5mm_P0.65mm; mpn OPA4197IPW

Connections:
+3.3VA: C1.2, C2.2, FB1.1, U2.5 (VDD)
+3V3: C3.2, FB1.2, J1.3, U2.11 (VLOGIC), U2.15 (~RESET), U2.16 (RSTSEL)
+12V: C5.2, J2.1, U3.4 (V+)
-10V: C4.2, R1.1, R3.2, R5.2, R7.2, R9.2, U1.2 (A)
-12V: C6.2, J2.2, R1.2, U3.11 (V-)
/CS: J1.6, U2.13 (~SYNC)
/DAC_OUT_A: R2.2, U2.3 (VOUTA)
/DAC_OUT_B: R4.2, U2.2 (VOUTB)
/DAC_OUT_C: R6.2, U2.6 (VOUTC)
/DAC_OUT_D: R8.2, U2.7 (VOUTD)
/OUT_A: J2.3, R10.1, R14.1
/OUT_B: J2.4, R11.1, R15.1
/OUT_C: J2.5, R12.1, R16.1
/OUT_D: J2.6, R13.1, R17.1
/SCLK: J1.4, U2.12 (SCLK)
/SDI: J1.5, U2.14 (SDIN)
/SDO: J1.7, U2.8 (SDO)
/VREF: J2.7, U2.1 (VREF)
GND: C1.1, C2.1, C3.1, C4.1, C5.1, C6.1, J1.1, J1.2, J1.8, J2.8, U1.1 (K), U2.4 (GND), U2.9 (~LDAC), U2.10 (GAIN), U3.3 (+), U3.5 (+), U3.10 (+), U3.12 (+)
unnamed: R2.1, R3.1, R10.2, U3.2 (-)
unnamed: R4.1, R5.1, R11.2, U3.6 (-)
unnamed: R6.1, R7.1, R12.2, U3.9 (-)
unnamed: R8.1, R9.1, R13.2, U3.13 (-)
unnamed: R14.2, U3.1
unnamed: R15.2, U3.7
unnamed: R16.2, U3.8
unnamed: R17.2, U3.14

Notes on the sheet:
Amplifies 0 V - 2.5 V to -8 V to 8 V Resolution: - 16-bit DAC: 0.25 mV - 14-bit DAC: 1 mV

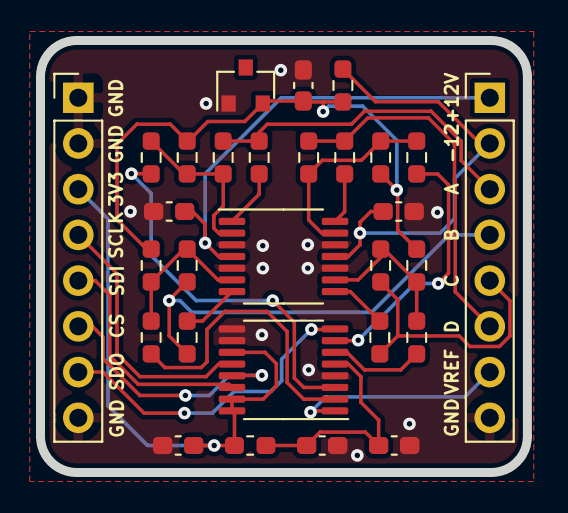
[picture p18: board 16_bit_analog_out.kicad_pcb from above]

Board: 2 copper layers, 27.1 x 24.0 mm, 29 parts (0 on the bottom side), 27 nets.

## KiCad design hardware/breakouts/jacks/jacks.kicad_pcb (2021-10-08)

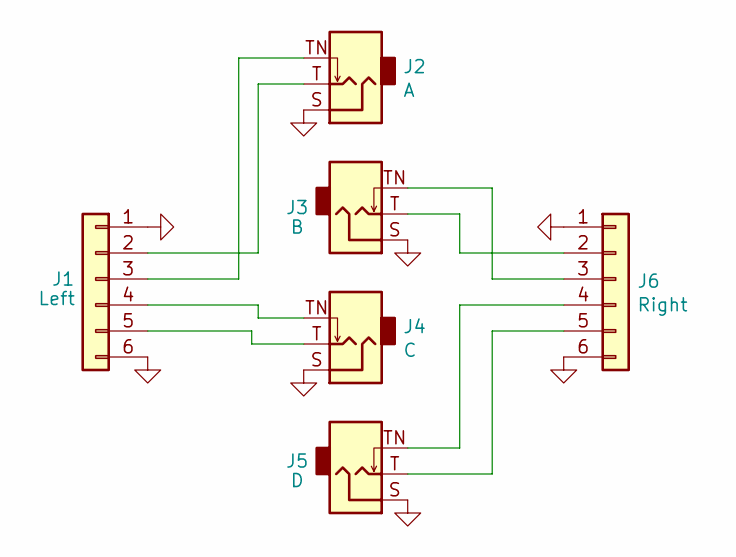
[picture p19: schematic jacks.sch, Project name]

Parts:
J1: Left; PinSocket_1x06_P2.54mm_Vertical
J2: A; WQP-WQP518MA; mpn WQP-WQP518MA
J3: B; WQP-WQP518MA; mpn WQP-WQP518MA
J4: C; WQP-WQP518MA; mpn WQP-WQP518MA
J5: D; WQP-WQP518MA; mpn WQP-WQP518MA
J6: Right; PinSocket_1x06_P2.54mm_Vertical

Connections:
GND: J1.1, J1.6, J2.S (Sleeve), J3.S (Sleeve), J4.S (Sleeve), J5.S (Sleeve), J6.1, J6.6
unnamed: J1.2, J2.T (Tip)
unnamed: J1.3, J2.TN (Tip_normalize)
unnamed: J1.4, J4.TN (Tip_normalize)
unnamed: J1.5, J4.T (Tip)
unnamed: J3.T (Tip), J6.2
unnamed: J3.TN (Tip_normalize), J6.3
unnamed: J5.T (Tip), J6.5
unnamed: J5.TN (Tip_normalize), J6.4

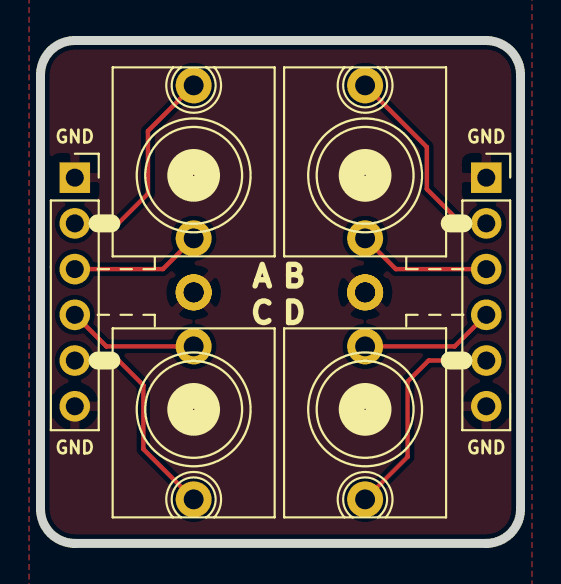
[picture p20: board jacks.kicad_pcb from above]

Board: 2 copper layers, 26.7 x 27.9 mm, 6 parts (0 on the bottom side), 9 nets.

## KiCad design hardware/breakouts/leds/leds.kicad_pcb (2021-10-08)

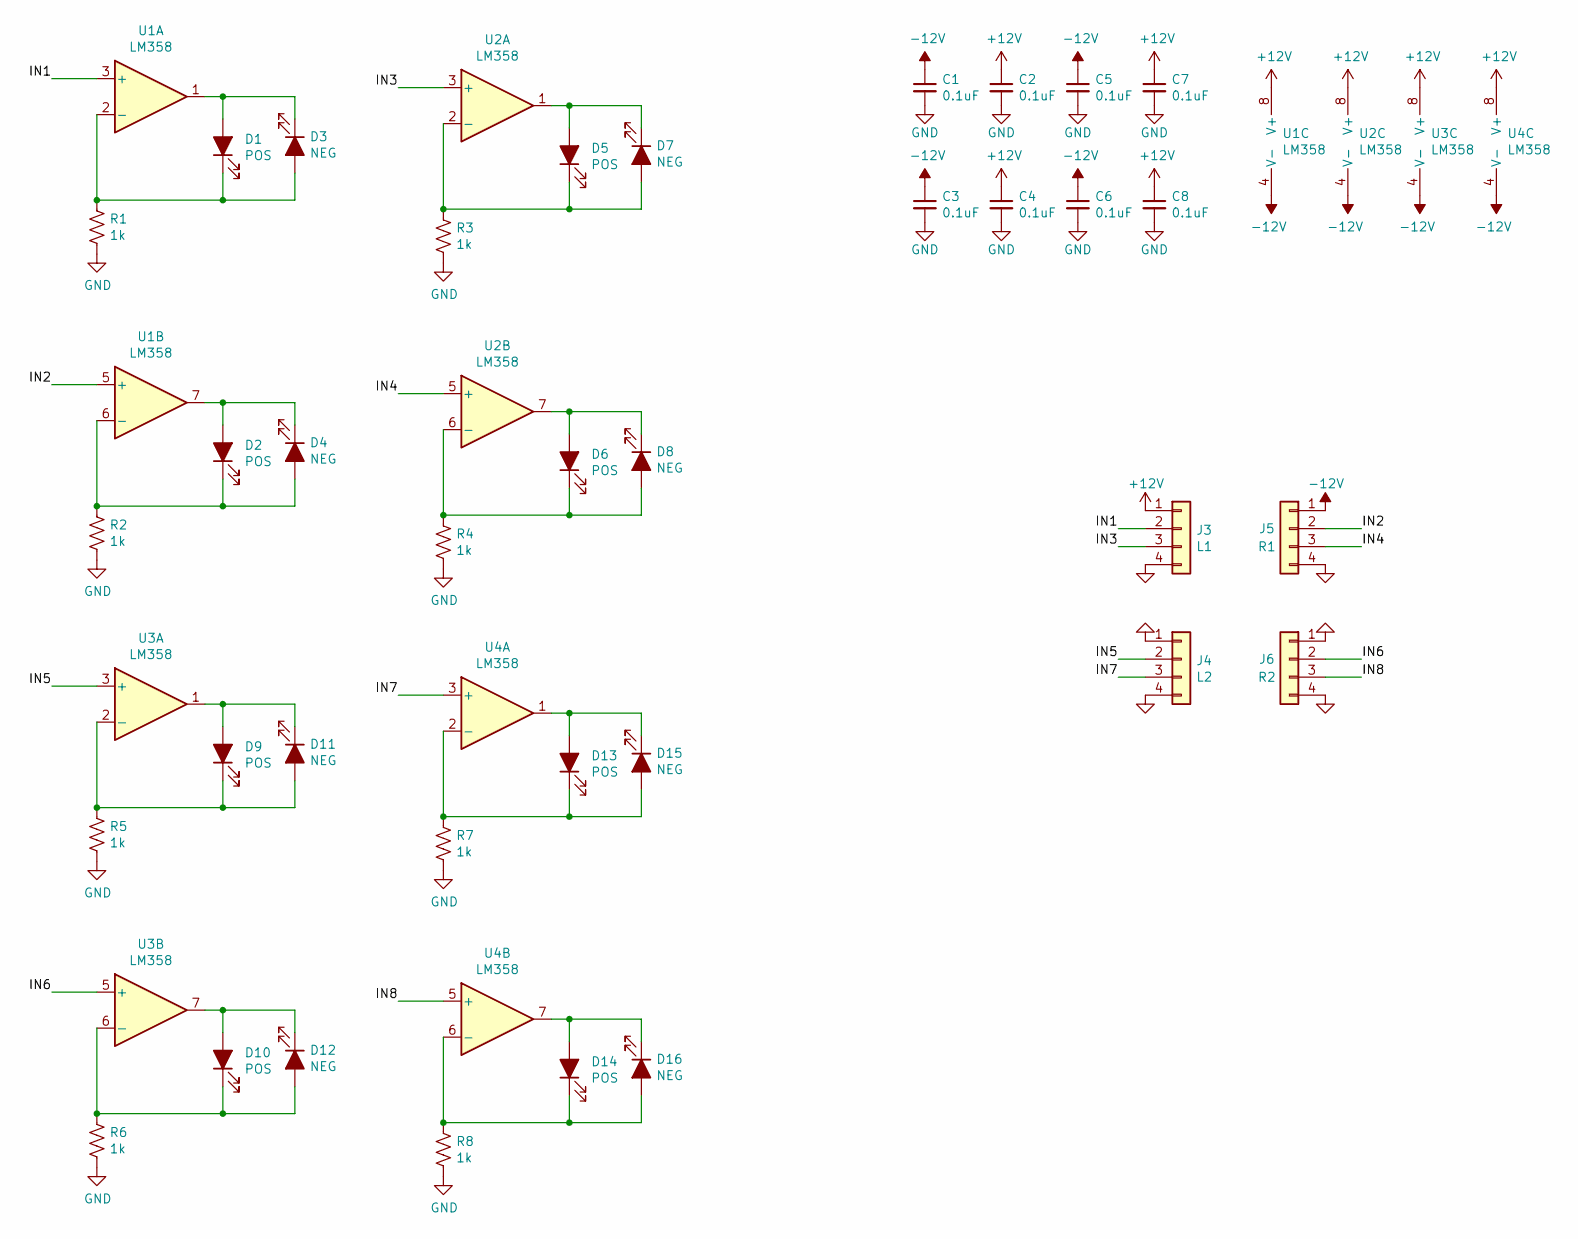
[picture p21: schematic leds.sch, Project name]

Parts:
C1, C2, C3, C4, C5, C6, C7, C8: 0.1uF; C_0603_1608Metric_Pad1.08x0.95mm_HandSolder
D1, D2, D5, D6, D9, D10, D13, D14: POS; LED_D3.0mm
D3, D4, D7, D8, D11, D12, D15, D16: NEG; LED_D3.0mm
J3: L1; PinSocket_1x04_P2.54mm_Vertical
J4: L2; PinSocket_1x04_P2.54mm_Vertical
J5: R1; PinSocket_1x04_P2.54mm_Vertical
J6: R2; PinSocket_1x04_P2.54mm_Vertical
R1, R2, R3, R4, R5, R6, R7, R8: 1k; R_0603_1608Metric_Pad0.98x0.95mm_HandSolder
U1, U2, U3, U4: LM358; TSSOP-8_4.4x3mm_P0.65mm

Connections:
+12V: C2.1, C4.1, C7.1, C8.1, J3.1, U1.8 (V+), U2.8 (V+), U3.8 (V+), U4.8 (V+)
-12V: C1.1, C3.1, C5.1, C6.1, J5.1, U1.4 (V-), U2.4 (V-), U3.4 (V-), U4.4 (V-)
/IN1: J3.2, U1.3 (+)
/IN2: J5.2, U1.5 (+)
/IN3: J3.3, U2.3 (+)
/IN4: J5.3, U2.5 (+)
/IN5: J4.2, U3.3 (+)
/IN6: J6.2, U3.5 (+)
/IN7: J4.3, U4.3 (+)
/IN8: J6.3, U4.5 (+)
GND: C1.2, C2.2, C3.2, C4.2, C5.2, C6.2, C7.2, C8.2, J3.4, J4.1, J4.4, J5.4, J6.1, J6.4, R1.2, R2.2, R3.2, R4.2, R5.2, R6.2, R7.2, R8.2
unnamed: D1.1 (K), D3.2 (A), R1.1, U1.2 (-)
unnamed: D1.2 (A), D3.1 (K), U1.1
unnamed: D2.1 (K), D4.2 (A), R2.1, U1.6 (-)
unnamed: D2.2 (A), D4.1 (K), U1.7
unnamed: D5.1 (K), D7.2 (A), R3.1, U2.2 (-)
unnamed: D5.2 (A), D7.1 (K), U2.1
unnamed: D6.1 (K), D8.2 (A), R4.1, U2.6 (-)
unnamed: D6.2 (A), D8.1 (K), U2.7
unnamed: D10.1 (K), D12.2 (A), R6.1, U3.6 (-)
unnamed: D10.2 (A), D12.1 (K), U3.7
unnamed: D9.2 (A), D11.1 (K), U3.1
unnamed: D9.1 (K), D11.2 (A), R5.1, U3.2 (-)
unnamed: D13.1 (K), D15.2 (A), R7.1, U4.2 (-)
unnamed: D13.2 (A), D15.1 (K), U4.1
unnamed: D14.1 (K), D16.2 (A), R8.1, U4.6 (-)
unnamed: D14.2 (A), D16.1 (K), U4.7


Board: 2 copper layers, 21.6 x 58.4 mm, 40 parts (0 on the bottom side), 27 nets.

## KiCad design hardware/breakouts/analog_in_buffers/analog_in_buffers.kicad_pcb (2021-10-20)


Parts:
C1, C4: 0.1uF; C_0603_1608Metric_Pad1.08x0.95mm_HandSolder
C2, C3, C5, C6: 22pF; C_0603_1608Metric_Pad1.08x0.95mm_HandSolder
J1: INPUT; PinHeader_1x06_P2.54mm_Vertical
J2: OUTPUT; PinHeader_1x06_P2.54mm_Vertical
R1, R3, R8, R10: 100k; R_0603_1608Metric_Pad0.98x0.95mm_HandSolder
R2, R4, R9, R11: 121k; R_0603_1608Metric_Pad0.98x0.95mm_HandSolder
R5: 1k; R_0603_1608Metric_Pad0.98x0.95mm_HandSolder
R6, R7, R12, R13: 18.7k; R_0603_1608Metric_Pad0.98x0.95mm_HandSolder
U1: LM4040-10; SOT-23; mpn LM4040DIM3-10.0/NOPB
U2: MCP6004; TSSOP-14_4.4x5mm_P0.65mm; mpn MCP6004T-I/ST, MCP6004T-E/ST

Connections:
+3V3: C4.1, J2.1, U2.4 (V+)
-10V: C1.2, R2.2, R4.2, R5.1, R9.2, R11.2, U1.2 (A)
-12V: J1.1, R5.2
/IN_A: J1.2, R1.2
/IN_B: J1.3, R3.2
/IN_C: J1.4, R10.2
/IN_D: J1.5, R8.2
/OUT_A: C2.2, J2.2, R6.1, U2.1
/OUT_B: C3.2, J2.3, R7.1, U2.7
/OUT_C: C6.2, J2.4, R13.1, U2.14
/OUT_D: C5.2, J2.5, R12.1, U2.8
GND: C1.1, C4.2, J1.6, J2.6, U1.1 (K), U2.3 (+), U2.5 (+), U2.10 (+), U2.11 (V-), U2.12 (+)
unnamed: C2.1, R1.1, R2.1, R6.2, U2.2 (-)
unnamed: C3.1, R3.1, R4.1, R7.2, U2.6 (-)
unnamed: C5.1, R8.1, R9.1, R12.2, U2.9 (-)
unnamed: C6.1, R10.1, R11.1, R13.2, U2.13 (-)

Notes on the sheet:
Inputs: -8V to +8V Outputs: 0v to 3.3V LPF Fc @ ???


Board: 2 copper layers, 27.1 x 18.5 mm, 23 parts (0 on the bottom side), 16 nets.

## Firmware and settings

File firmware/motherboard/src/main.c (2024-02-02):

/*
    Copyright (c) 2021 Alethea Katherine Flowers.
    Published under the standard MIT License.
    Full text available at: https://opensource.org/licenses/MIT
*/

#include "hubble.h"
#include "printf.h"
#include "wntr_array.h"
#include "wntr_build_info.h"
#include "wntr_colorspace.h"
#include "wntr_data_converter_helpers.h"
#include "wntr_delay.h"
#include "wntr_gpio.h"
#include "wntr_sysex_utils.h"
#include "wntr_ticks.h"
#include <math.h>
#include <stdlib.h>
#include <string.h>

/* Macros */

/* Global state */

static bool calibration_enabled = false;

/* Forward declarations */

int main(void);
static void init();
static void init_dacs();
static void loop();
static void register_sysex_commands();

WNTR_SYSEX_COMMAND_DECL(0x01, hello);
WNTR_SYSEX_COMMAND_DECL(0x02, reset);
WNTR_SYSEX_COMMAND_DECL(0x03, read_gpio);
WNTR_SYSEX_COMMAND_DECL(0x04, set_gpio);
WNTR_SYSEX_COMMAND_DECL(0x05, read_adc);
WNTR_SYSEX_COMMAND_DECL(0x06, read_adc_voltage);
WNTR_SYSEX_COMMAND_DECL(0x07, set_dac);
WNTR_SYSEX_COMMAND_DECL(0x08, set_dac_voltage);
WNTR_SYSEX_COMMAND_DECL(0x50, set_calibration_enabled);
WNTR_SYSEX_COMMAND_DECL(0x51, set_calibration_table_entry);
WNTR_SYSEX_COMMAND_DECL(0x52, save_calibration_table);

/* Public functions */

int main(void) {
    init();
    printf("Hello, I'm Hubble!\n");

    while (1) {
        wntr_usb_task();
        loop();
    }

    return 0;
}

/* Private functions */

static void init() {
    SystemInit();

    /* Turn on the "alive" LED */
    WntrGPIOPin_set_as_output(PIN_STATUS_LED);
    WntrGPIOPin_set(PIN_STATUS_LED, true);

    /* Setup USB as soon as possible */
    wntr_usb_init();

    /* Dotstars */
    WntrSERCOMSPI_init(&DOTSTAR_SPI);
    hubble_dotstar_init(&DOTSTAR_SPI, 20);

    /* ADC */
    hubble_adc_init();
    hubble_adc_init_inputs(AIN, WNTR_ARRAY_LEN(AIN));

    /* SPI bus & external DAC */
    WntrSERCOMSPI_init(&AD5685_SPI);
    hubble_ad5685_init(&AD5685_SPI);
    hubble_ad5685_soft_reset();

    /* Calibrations */
    hubble_calibration_tables_init(calibration_enabled);

    /* Set initial values for dacs and muxes */
    init_dacs();

    /* Sysex commands */
    register_sysex_commands();
}

static void init_dacs() {
    return;
    // Yes, slightly above zero, since MCU inputs tend to be
    // more forgiving of a very small positive voltage than any negative
    // voltage.
    uint32_t zero_code_point = wntr_volts_to_code_points(0.1f, WNTR_RESOLUTION_16_BIT, -8.0f, 8.0f, true);
    hubble_ad5685_write_channel(0, zero_code_point, true);
    hubble_ad5685_write_channel(1, zero_code_point, true);
    hubble_ad5685_write_channel(2, zero_code_point, true);
    hubble_ad5685_write_channel(3, zero_code_point, true);
}

static void loop() {
    /* Blink the LED */
    if ((wntr_ticks() / 100) % 2 == 0) {
        WntrGPIOPin_set(PIN_STATUS_LED, true);
    } else {
        WntrGPIOPin_set(PIN_STATUS_LED, false);
    }

    /* Dotstar update */
    static uint16_t hue = 0;
    hubble_dotstar_set32(0, wntr_colorspace_hsv_to_rgb(hue, 200, 255));
    hubble_dotstar_update();
    hue += 10;

    /* MIDI I/O update */
    struct WntrMIDIMessage midi_msg = {};

    if (wntr_midi_receive(&midi_msg)) {
        if (midi_msg.code_index == MIDI_CODE_INDEX_SYSEX_START_OR_CONTINUE) {
            wntr_midi_dispatch_sysex();
        }
    }
}

static void register_sysex_commands() {
    WNTR_REGISTER_SYSEX_COMMAND(0x01, hello);
    WNTR_REGISTER_SYSEX_COMMAND(0x02, reset);
    WNTR_REGISTER_SYSEX_COMMAND(0x03, read_gpio);
    WNTR_REGISTER_SYSEX_COMMAND(0x04, set_gpio);
    WNTR_REGISTER_SYSEX_COMMAND(0x05, read_adc);
    WNTR_REGISTER_SYSEX_COMMAND(0x06, read_adc_voltage);
    WNTR_REGISTER_SYSEX_COMMAND(0x07, set_dac);
    WNTR_REGISTER_SYSEX_COMMAND(0x08, set_dac_voltage);
    WNTR_REGISTER_SYSEX_COMMAND(0x50, set_calibration_enabled);
    WNTR_REGISTER_SYSEX_COMMAND(0x51, set_calibration_table_entry);
    WNTR_REGISTER_SYSEX_COMMAND(0x52, save_calibration_table);
}

WNTR_SYSEX_COMMAND_DECL(0x01, hello) {
    /*
        Response: 0x01 and the build info string, for example:
        "12.24.2020 on 20/01/2021 23:38 UTC with arm-none-eabi-gcc 10.2.1 20201103 (release) by
        stargirl@stargirls-mbp.lan"
    */

    const char* build_info = wntr_build_info_string();
    size_t build_info_len = strlen(build_info);

    WNTR_SYSEX_PREPARE_RESPONSE(0x01, 128);

    /* Don't copy more of the build info string than we have room for. */
    if (build_info_len > response_len) {
        build_info_len = response_len;
    }

    memccpy(response, build_info, 0, 128);

    WNTR_SYSEX_SEND_RESPONSE();

    printf("SysEx 0x01: Hello! Build info length: %u\n", build_info_len);
}

WNTR_SYSEX_COMMAND_DECL(0x02, reset) {
    /* Response: None */
    printf("SysEx 0x02: Reset requested\n");
    NVIC_SystemReset();
}

WNTR_SYSEX_COMMAND_DECL(0x03, read_gpio) {
    /* Request: GPIO Pin (1) */
    /* Response: Value (1) */

    uint8_t pin = request_data[0];

    if (pin > WNTR_ARRAY_LEN(GPIO) - 1) {
        pin = WNTR_ARRAY_LEN(GPIO) - 1;
    }

    WntrGPIOPin_set_as_input(GPIO[pin], false);

    uint8_t result = WntrGPIOPin_get(GPIO[pin]);

    WNTR_SYSEX_RESPONSE_UNARY(0x03, result);

    printf("SysEx 0x03: Read GPIO %u, result %u\n", pin, result);
}

WNTR_SYSEX_COMMAND_DECL(0x04, set_gpio) {
    /* Request: GPIO Pin (1), value (1) */
    /* Response: ACK */

    uint8_t pin = request_data[0];
    uint8_t value = request_data[1];

    if (pin > WNTR_ARRAY_LEN(GPIO) - 1) {
        pin = WNTR_ARRAY_LEN(GPIO) - 1;
    }

    WntrGPIOPin_set_as_output(GPIO[pin]);
    WntrGPIOPin_set(GPIO[pin], value ? true : false);

    WNTR_SYSEX_RESPONSE_NULLARY(0x04);

    printf("SysEx 0x04: Set GPIO %u to %u\n", pin, value);
}

WNTR_SYSEX_COMMAND_DECL(0x05, read_adc) {
    /* Request: CHANNEL(1) */
    /* Response (teeth): VALUE(2) */

    uint8_t channel = request_data[0];

    if (channel > WNTR_ARRAY_LEN(AIN) - 1) {
        channel = WNTR_ARRAY_LEN(AIN) - 1;
    }

    uint16_t result = hubble_adc_read_sync(AIN[channel]);

    WNTR_SYSEX_PREPARE_RESPONSE(0x05, TEETH_ENCODED_LENGTH(2));

    uint8_t unencoded_response[2];
    WNTR_PACK_16(result, unencoded_response, 0);
    teeth_encode(unencoded_response, 2, response);

    WNTR_SYSEX_SEND_RESPONSE();

    printf("SysEx 0x05: Read AIN %u, result %u\n", channel, result);
}

WNTR_SYSEX_COMMAND_DECL(0x06, read_adc_voltage) {
    /* Request: CHANNEL(1) */
    /* Response (teeth): VALUE(4) */
    uint8_t channel = request_data[0];

    if (channel > WNTR_ARRAY_LEN(AIN) - 1) {
        channel = WNTR_ARRAY_LEN(AIN) - 1;
    }

    uint16_t code_points = hubble_adc_read_sync(AIN[channel]);

    float result = wntr_code_points_to_volts(code_points, WNTR_RESOLUTION_12_BIT, -8.0f, 8.0f, true);

    if (calibration_enabled) {
        result = WntrVoltageCalibrationTable_lookup(result, *hubble_adc_calibration_tables[channel]);
    } else {
        printf("Warning: calibration tables disabled.\n");
    }

    WNTR_SYSEX_PREPARE_RESPONSE(0x06, TEETH_ENCODED_LENGTH(4));

    uint8_t unencoded_response[4];
    WNTR_PACK_FLOAT(result, unencoded_response, 0);
    teeth_encode(unencoded_response, 4, response);

    WNTR_SYSEX_SEND_RESPONSE();

    printf("SysEx 0x06: Read ADC voltage %u is %0.3f\n", channel, (double)(result));
}

WNTR_SYSEX_COMMAND_DECL(0x07, set_dac) {
    /* Request (teeth): CHANNEL(1) VALUE(2) */
    /* Response: ACK */

    WNTR_SYSEX_DECODE_TEETH_REQUEST(3);

    uint8_t channel = request[0];
    uint16_t value = WNTR_UNPACK_16(request, 1);

    if (channel > 15) {
        channel = 15;
    }

    hubble_ad5685_write_channel(channel, value, true);

    WNTR_SYSEX_RESPONSE_NULLARY();

    printf("SysEx 0x07: Set DAC %u to %u\n", channel, value);
}

WNTR_SYSEX_COMMAND_DECL(0x08, set_dac_voltage) {
    /* Request (teeth): CHANNEL(1) VALUE(4) */
    /* Response: ACK */

    WNTR_SYSEX_DECODE_TEETH_REQUEST(5);

    uint8_t channel = request[0];
    float value = WNTR_UNPACK_FLOAT(request, 1);

    if (channel > 15) {
        channel = 15;
    }

    if (calibration_enabled) {
        value = WntrVoltageCalibrationTable_lookup(value, *hubble_dac_calibration_tables[channel]);
    } else {
        printf("Warning: calibration tables disabled.\n");
    }

    uint32_t code_point = wntr_volts_to_code_points(value, WNTR_RESOLUTION_16_BIT, -8.0f, 8.0f, true);

    hubble_ad5685_write_channel(channel, code_point, true);

    WNTR_SYSEX_RESPONSE_NULLARY();

    printf("SysEx 0x08: Set DAC voltage %u to %0.3f\n", channel, (double)(value));
}

WNTR_SYSEX_COMMAND_DECL(0x50, set_calibration_enabled) {
    /* Request: ENABLED(1) */
    /* Response: ACK */

    calibration_enabled = request_data[0] ? true : false;

    WNTR_SYSEX_RESPONSE_NULLARY();

    printf("SysEx 0x50: Set calibration enabled to: %u\n", calibration_enabled);
}

WNTR_SYSEX_COMMAND_DECL(0x51, set_calibration_table_entry) {
    /* Request (teeth): ADC/DAC(1) TABLE(1) INDEX(1) EXPECTED(4), MEASURED(4) */
    /* Response: ACK */

    WNTR_SYSEX_DECODE_TEETH_REQUEST(11);

    uint8_t adc_or_dac = request[0];
    uint8_t table_idx = request[1];
    uint8_t index = request[2];
    float expected = WNTR_UNPACK_FLOAT(request, 3);
    float measured = WNTR_UNPACK_FLOAT(request, 7);

    struct WntrVoltageCalibrationTable** tables =
        adc_or_dac ? hubble_dac_calibration_tables : hubble_adc_calibration_tables;
    struct WntrVoltageCalibrationTable* table = tables[table_idx];

    table->entries[index].expected = expected;
    table->entries[index].measured = measured;

    WNTR_SYSEX_RESPONSE_NULLARY();

    printf(
        "SysEx 0x51: Set %s calibration table %u[%u] to expected=%0.3f, measured=%0.3f\n",
        adc_or_dac ? "DAC" : "ADC",
        table,
        index,
        (double)expected,
        (double)measured);
}

WNTR_SYSEX_COMMAND_DECL(0x52, save_calibration_table) {
    /* Request: ADC/DAC(1) TABLE(1) */
    /* Response: ACK */

    uint8_t adc_or_dac = request_data[0];
    uint8_t table_idx = request_data[1];

    size_t bank_offset = adc_or_dac ? 16 : 0;
    struct WntrVoltageCalibrationTable** tables =
        adc_or_dac ? hubble_dac_calibration_tables : hubble_adc_calibration_tables;
    struct WntrVoltageCalibrationTable* table = tables[table_idx];

    HubbleVoltageCalibrationTable_save_to_nvm(*table, bank_offset + table_idx);

    WNTR_SYSEX_RESPONSE_NULLARY();

    printf("SysEx 0x52: Save %s calibration table %u\n", adc_or_dac ? "DAC" : "ADC", table);
    WntrVoltageCalibrationTable_print(*table);
}

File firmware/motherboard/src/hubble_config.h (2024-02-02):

/*
    Copyright (c) 2021 Alethea Katherine Flowers.
    Published under the standard MIT License.
    Full text available at: https://opensource.org/licenses/MIT
*/

#pragma once

/* Global configuration for all of Hubble's hardware and behavior. */

#include "hubble_adc.h"
#include "hubble_dac.h"
#include "hubble_mux50x.h"
#include "sam.h"
#include "wntr_bitbang_spi.h"
#include "wntr_gpio.h"
#include "wntr_sercom_spi.h"
#include <stdint.h>

/*
    Clock configuration
*/
#define WNTR_SYSTEM_CLOCKS_USE_32K_CRYSTAL 1

/*
    ADC/DAC configuration
*/

#define HUBBLE_ADC0_ENABLED 1
#define HUBBLE_ADC1_ENABLED 1

/* 48 MHz clock divided down to 12 MHz, or around 750 KSPS. */
#define HUBBLE_ADC_GCLK GCLK_PCHCTRL_GEN_GCLK1
#define HUBBLE_ADC_PRESCALER ADC_CTRLA_PRESCALER_DIV4

/*
    The ADC inputs are driven by low impedence op-amps (let's assume 1 kOhms),
    so the sample time doesn't need to be very high. (Datasheet Figure 54-4)

    sample_time >= (2 kOhms + 1 kOhms) * 3 pF * 9.7
    sample_time >= 87.3 ns

    With the clock at 12 MHz (83 ns period), 2 clock cycles should be
    sufficient.
*/
#define HUBBLE_ADC_SAMPLE_TIME 2

/*
    Averaging reduces the througput by 1 / SAMPLENUM, so with 750 KSPS
    we'll end up with 46 KSPS, divided amongst the ADC channels.
    See Datasheet table 45-3.
*/
#define HUBBLE_ADC_AVERAGE_SAMPLENUM ADC_AVGCTRL_SAMPLENUM_16
#define HUBBLE_ADC_AVERAGE_ADJRES 0x4

/*
    Special purpose pins
*/
#define PIN_STATUS_LED (WNTR_GPIO_PIN(A, 27))
#define PIN_DS_POWER_EN (WNTR_GPIO_PIN(C, 1))
#define PIN_SDO (WNTR_GPIO_PIN_ALT(B, 30, H))

/*
    Serial exclusive pins, can also be used as GPIO
*/
#define SER_1_0 (WNTR_GPIO_PIN_ALT(A, 16, C_SERCOM))
#define SER_1_1 (WNTR_GPIO_PIN_ALT(A, 17, C_SERCOM))
#define SER_1_2 (WNTR_GPIO_PIN_ALT(A, 18, C_SERCOM))
#define SER_1_3 (WNTR_GPIO_PIN_ALT(A, 19, C_SERCOM))

#define SER_2_0 (WNTR_GPIO_PIN_ALT(A, 12, C_SERCOM))
#define SER_2_1 (WNTR_GPIO_PIN_ALT(A, 13, C_SERCOM))
#define SER_2_2 (WNTR_GPIO_PIN_ALT(A, 14, C_SERCOM))
#define SER_2_3 (WNTR_GPIO_PIN_ALT(A, 15, C_SERCOM))

/*
    GPIO exclusive pins
*/
#define GPIO_1 (WNTR_GPIO_PIN(D, 20))
#define GPIO_2 (WNTR_GPIO_PIN(C, 23))
#define GPIO_3 (WNTR_GPIO_PIN(C, 22))
#define GPIO_4 (WNTR_GPIO_PIN(C, 21))
#define GPIO_5 (WNTR_GPIO_PIN(C, 20))
#define GPIO_6 (WNTR_GPIO_PIN(C, 19))
#define GPIO_7 (WNTR_GPIO_PIN(C, 12))
#define GPIO_8 (WNTR_GPIO_PIN(C, 11))
#define GPIO_9 (WNTR_GPIO_PIN(C, 10))
#define GPIO_10 (WNTR_GPIO_PIN(D, 12))
#define GPIO_11 (WNTR_GPIO_PIN(D, 11))
#define GPIO_12 (WNTR_GPIO_PIN(D, 10))
#define GPIO_13 (WNTR_GPIO_PIN(D, 9))
#define GPIO_14 (WNTR_GPIO_PIN(D, 8))
#define GPIO_15 (WNTR_GPIO_PIN(B, 15))
#define GPIO_16 (WNTR_GPIO_PIN(B, 14))
#define GPIO_17 (WNTR_GPIO_PIN(B, 12))
#define GPIO_18 (WNTR_GPIO_PIN(B, 11))
#define GPIO_19 (WNTR_GPIO_PIN(B, 10))
#define GPIO_20 (WNTR_GPIO_PIN(C, 7))
#define GPIO_21 (WNTR_GPIO_PIN(C, 6))
#define GPIO_22 (WNTR_GPIO_PIN(C, 5))
#define GPIO_23 (WNTR_GPIO_PIN(C, 4))

/*
    Array of all GPIO pins
*/
static const struct WntrGPIOPin GPIO[] = {
    GPIO_1,  GPIO_2,  GPIO_3,  GPIO_4,  GPIO_5,  GPIO_6,  GPIO_7,  GPIO_8,  GPIO_9,  GPIO_10,        GPIO_11,
    GPIO_12, GPIO_13, GPIO_14, GPIO_15, GPIO_16, GPIO_17, GPIO_18, GPIO_19, GPIO_20, GPIO_21,        GPIO_22,
    GPIO_23, SER_1_0, SER_1_1, SER_1_2, SER_1_3, SER_2_0, SER_2_1, SER_2_2, SER_2_3, PIN_STATUS_LED, PIN_DS_POWER_EN,
};

/*
    ADC exclusive pins with buffers
*/
#define AIN_VREFA (HUBBLE_ADC_INPUT(ADC0, 1, A, 3))
#define VIN_1 (HUBBLE_ADC_INPUT(ADC1, 5, C, 3))
#define VIN_2 (HUBBLE_ADC_INPUT(ADC1, 6, B, 4))
#define VIN_3 (HUBBLE_ADC_INPUT(ADC1, 7, B, 5))
#define VIN_4 (HUBBLE_ADC_INPUT(ADC1, 14, D, 0))
#define VIN_5 (HUBBLE_ADC_INPUT(ADC1, 15, D, 1))
#define VIN_6 (HUBBLE_ADC_INPUT(ADC1, 8, B, 6))
#define VIN_7 (HUBBLE_ADC_INPUT(ADC1, 9, B, 7))
#define VIN_8 (HUBBLE_ADC_INPUT(ADC0, 2, B, 8))
#define VIN_9 (HUBBLE_ADC_INPUT(ADC0, 3, B, 9))
#define VIN_10 (HUBBLE_ADC_INPUT(ADC0, 4, A, 4))
#define VIN_11 (HUBBLE_ADC_INPUT(ADC0, 6, A, 6))
#define VIN_12 (HUBBLE_ADC_INPUT(ADC0, 7, A, 7))
#define AIN_1 (HUBBLE_ADC_INPUT(ADC0, 8, A, 8))
#define AIN_2 (HUBBLE_ADC_INPUT(ADC0, 9, A, 9))
#define AIN_3 (HUBBLE_ADC_INPUT(ADC0, 10, A, 10))
#define AIN_4 (HUBBLE_ADC_INPUT(ADC0, 11, A, 11))

static const struct HubbleADCInput AIN[] = {
    VIN_1,
    VIN_2,
    VIN_3,
    VIN_4,
    VIN_5,
    VIN_6,
    VIN_7,
    VIN_8,
    VIN_9,
    VIN_10,
    VIN_11,
    VIN_12,
    AIN_1,
    AIN_2,
    AIN_3,
    AIN_4,
};

/*
    SPI configuration for Dotstars
*/
static const struct WntrSERCOMSPI DOTSTAR_SPI = {
    .sercom = &SERCOM3->SPI,
    .dopo = SERCOM_SPI_DOPO_SDO_0_SCK_1_CS_2,
    .sdo = WNTR_GPIO_PIN_ALT(A, 22, C_SERCOM),
    .sck = WNTR_GPIO_PIN_ALT(A, 23, C_SERCOM),
    // No CS pin, so this is just an unused pin
    .cs = WNTR_GPIO_PIN_ALT(A, 21, NONE),
    .polarity = 0,
    .phase = 0,
};
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

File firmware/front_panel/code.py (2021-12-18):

import time

import adafruit_displayio_sh1107
import board
import digitalio
import displayio
import pwmio
import rotaryio
import terminalio
import usb_hid
import usb_midi
from adafruit_display_text import bitmap_label
from adafruit_hid.keyboard import Keyboard
from adafruit_hid.keyboard_layout_us import KeyboardLayoutUS
from adafruit_hid.keycode import Keycode
import adafruit_imageload

import smolmidi

# Buttons and bows


class Button:
    def __init__(self, pin):
        self.io = digitalio.DigitalInOut(pin)
        self.io.switch_to_input(pull=digitalio.Pull.UP)
        self.last_value = self.io.value
        self.current_value = self.last_value

    def update(self):
        self.last_value = self.current_value
        self.current_value = self.io.value

    @property
    def value(self):
        return self.current_value

    @property
    def pressed(self):
        return self.last_value is True and self.current_value is False

    @property
    def released(self):
        return self.last_value is False and self.current_value is True


class KeyboardButton:
    def __init__(self, button, value):
        self.button = button
        self.value = value

    def update(self):
        if self.button.pressed:
            if isinstance(self.value, str):
                KEYBOARD_LAYOUT.write(self.value)
            elif isinstance(self.value, tuple):
                KEYBOARD.send(*self.value)
            else:
                KEYBOARD.send(self.value)


class Encoder:
    def __init__(self, pin_1, pin_2, reverse=False):
        self.io = rotaryio.IncrementalEncoder(pin_1, pin_2)
        self.reverse = reverse
        self.last_position = 0
        self.current_position = 0

    def update(self):
        self.last_position = self.current_position

        if not self.reverse:
            self.current_position = self.io.position
        else:
            self.current_position = -self.io.position

    @property
    def position(self):
        return self.current_position

    @property
    def delta(self):
        return self.current_position - self.last_position

    @property
    def increased(self):
        return self.last_position < self.current_position

    @property
    def decreased(self):
        return self.last_position > self.current_position


class LED:
    NORMAL = 0
    OFF = 1
    ON = 2
    FLASHING = 3
    BREATHING = 4

    def __init__(self, pin):
        self.io = pwmio.PWMOut(pin)
        self.mode = self.NORMAL
        self.brightness = 0

    @property
    def brightness(self):
        return 0

    @brightness.setter
    def brightness(self, val):
        self.io.duty_cycle = min(65535, max(int(65535 * val), 0))

    def update(self):
        if self.mode == self.NORMAL:
            pass
        elif self.mode == self.OFF:
            self.brightness = 0
        elif self.mode == self.ON:
            self.brightness = 1
        elif self.mode == self.FLASHING:
            self.brightness = (time.monotonic() * 4) % 1.0
        elif self.mode == self.BREATHING:
            self.brightness = abs(-1 + ((time.monotonic() / 2) % 1.0) * 2)


def chunks(lst, n):
    """Yield successive n-sized chunks from lst."""
    for i in range(0, len(lst), n):
        yield lst[i : i + n]


# Keyboard, gamepad and such

KEYBOARD = Keyboard(usb_hid.devices)
KEYBOARD_LAYOUT = KeyboardLayoutUS(KEYBOARD)

# I/O

ENCODER = Encoder(board.D9, board.D10, reverse=True)

GREEN_BTN_1 = Button(board.TX)
GREEN_BTN_1_KB = KeyboardButton(GREEN_BTN_1, "python3 factory_setup.py\n")
GREEN_BTN_2 = Button(board.D12)
GREEN_BTN_2_KB = KeyboardButton(GREEN_BTN_2, Keycode.ENTER)
RED_BTN = Button(board.D11)
RED_BTN_KB = KeyboardButton(RED_BTN, (Keycode.CONTROL, Keycode.C))
ENCODER_BTN = Button(board.D4)
ENCODER_BTN_KB = KeyboardButton(ENCODER_BTN, Keycode.KEYPAD_ENTER)
SECOND_SWITCH = Button(board.RX)
SECOND_SWITCH_KB = KeyboardButton(SECOND_SWITCH, Keycode.SPACE)
POWER_SWITCH = Button(board.MISO)

BLUE_LED = LED(board.D13)
GREEN_LED = LED(board.D6)
RED_LED = LED(board.D5)

# MIDI

midi_in = smolmidi.MidiIn(usb_midi.ports[0])

# Display
I2C = board.I2C()
displayio.release_displays()
display_bus = displayio.I2CDisplay(I2C, device_address=0x3C)
display = adafruit_displayio_sh1107.SH1107(
    display_bus, width=128, height=64, rotation=0
)
display.auto_refresh = True
display_group = displayio.Group()
display.show(display_group)

text = bitmap_label.Label(
    terminalio.FONT, text="Idle", scale=2, color=0xFFFFFF, x=0, y=10
)
display_group.append(text)

oh_no_bitmap, oh_no_palette = adafruit_imageload.load(
    "/ohno.bmp", bitmap=displayio.Bitmap, palette=displayio.Palette
)
oh_no_tile_grid = displayio.TileGrid(oh_no_bitmap, pixel_shader=oh_no_palette)
oh_no_tile_grid.hidden = True

# Now the fun stuff.
RED_LED.mode = LED.BREATHING

while True:
    POWER_SWITCH.update()
    ENCODER.update()
    GREEN_BTN_1.update()
    GREEN_BTN_1_KB.update()
    GREEN_BTN_2.update()
    GREEN_BTN_2_KB.update()
    RED_BTN.update()
    RED_BTN_KB.update()
    ENCODER_BTN.update()
    ENCODER_BTN_KB.update()
    SECOND_SWITCH.update()
    SECOND_SWITCH_KB.update()

    if ENCODER.increased:
        for _ in range(ENCODER.delta):
            KEYBOARD.send(Keycode.RIGHT_ARROW)
    elif ENCODER.decreased:
        for _ in range(abs(ENCODER.delta)):
            KEYBOARD.send(Keycode.LEFT_ARROW)

    if POWER_SWITCH.pressed:
        text.text = "Ready!"
    elif POWER_SWITCH.released:
        GREEN_LED.mode = GREEN_LED.OFF
        RED_LED.mode = GREEN_LED.OFF
        text.text = "Idle"

    BLUE_LED.update()
    GREEN_LED.update()
    RED_LED.update()

    msg = midi_in.receive()
    if msg:
        if msg.type == smolmidi.NOTE_ON:
            led_num = msg.data[0] & 0x0F
            led_mode = (msg.data[0] & 0xF0) >> 4

            if led_num == 0:
                led = BLUE_LED
            elif led_num == 1:
                led = GREEN_LED
            else:
                led = RED_LED

            led.brightness = msg.data[1] / 127
            led.mode = led_mode

        if msg.type == smolmidi.SYSEX:
            data, _ = midi_in.receive_sysex(128)
            if not data:
                continue

            command = data[1]

            if command == 0x01:
                new_text = bytes(data[2:]).decode("ascii")
                lines = "\n".join(line.strip() for line in chunks(new_text, 10))
                text.text = lines
                if not oh_no_tile_grid.hidden:
                    oh_no_tile_grid.hidden = True
                    display_group.pop()

            elif command == 0x02:
                oh_no_tile_grid.hidden = False
                display_group.append(oh_no_tile_grid)

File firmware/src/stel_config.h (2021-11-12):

/*
    Copyright (c) 2021 Alethea Katherine Flowers.
    Published under the standard MIT License.
    Full text available at: https://opensource.org/licenses/MIT
*/

#pragma once

/* Global configuration for all of Stellar's hardware and behavior. */

#include "sam.h"
#include "stel_adc.h"
#include "stel_dac.h"
#include "stel_sercom_spi.h"
#include "wntr_bitbang_spi.h"
#include "wntr_gpio.h"
#include <stdint.h>

/*
    Clock configuration
*/
#define STEL_HAS_CRYSTAL 1

/*
    ADC/DAC configuration
*/

#define STEL_ADC0_ENABLED 1
#define STEL_ADC1_ENABLED 1

/* 48 MHz clock divided down to 12 MHz, or around 750 KSPS. */
#define STEL_ADC_GCLK GCLK_PCHCTRL_GEN_GCLK1
#define STEL_ADC_PRESCALER ADC_CTRLA_PRESCALER_DIV4

/*
    The ADC inputs are driven by low impedence op-amps (let's assume 1 kOhms),
    so the sample time doesn't need to be very high. (Datasheet Figure 54-4)

    sample_time >= (2 kOhms + 1 kOhms) * 3 pF * 9.7
    sample_time >= 87.3 ns

    With the clock at 12 MHz (83 ns period), 2 clock cycles should be
    sufficient.
*/
#define STEL_ADC_SAMPLE_TIME 2

/*
    Averaging reduces the througput by 1 / SAMPLENUM, so with 750 KSPS
    we'll end up with 46 KSPS, divided amongst the ADC channels.
    See Datasheet table 45-3.
*/
#define STEL_ADC_AVERAGE_SAMPLENUM ADC_AVGCTRL_SAMPLENUM_16
#define STEL_ADC_AVERAGE_ADJRES 0x4

/*
    Pin assignments
*/
#define GPIO_1 (WNTR_GPIO_PIN(WNTR_PORT_A, 27))
#define GPIO_2 (WNTR_GPIO_PIN(WNTR_PORT_B, 23))
#define GPIO_3 (WNTR_GPIO_PIN(WNTR_PORT_B, 22))
#define GPIO_4 (WNTR_GPIO_PIN(WNTR_PORT_A, 21))
#define GPIO_5 (WNTR_GPIO_PIN(WNTR_PORT_A, 20))
#define GPIO_6 (WNTR_GPIO_PIN(WNTR_PORT_A, 12))
#define GPIO_7 (WNTR_GPIO_PIN(WNTR_PORT_B, 11))
#define GPIO_8 (WNTR_GPIO_PIN(WNTR_PORT_B, 10))
#define GPIO_9 (WNTR_GPIO_PIN(WNTR_PORT_A, 11))
#define GPIO_9_ADC_0_11 ((const struct StelADCInput){ADC0, WNTR_PORT_A, 11, ADC_INPUTCTRL_MUXPOS_AIN11})
#define GPIO_10 (WNTR_GPIO_PIN(WNTR_PORT_A, 10))
#define GPIO_10_ADC_0_10 ((const struct StelADCInput){ADC0, WNTR_PORT_A, 10, ADC_INPUTCTRL_MUXPOS_AIN10})
#define GPIO_11 (WNTR_GPIO_PIN(WNTR_PORT_A, 9))
#define GPIO_11_ADC_0_9 ((const struct StelADCInput){ADC0, WNTR_PORT_A, 9, ADC_INPUTCTRL_MUXPOS_AIN9})
#define GPIO_11_ADC_1_3 ((const struct StelADCInput){ADC1, WNTR_PORT_A, 9, ADC_INPUTCTRL_MUXPOS_AIN3})
#define GPIO_12 (WNTR_GPIO_PIN(WNTR_PORT_A, 8))
#define GPIO_12_ADC_0_8 ((const struct StelADCInput){ADC0, WNTR_PORT_A, 8, ADC_INPUTCTRL_MUXPOS_AIN8})
#define GPIO_12_ADC_1_2 ((const struct StelADCInput){ADC1, WNTR_PORT_A, 8, ADC_INPUTCTRL_MUXPOS_AIN2})
#define GPIO_13 (WNTR_GPIO_PIN(WNTR_PORT_A, 7))
#define GPIO_13_ADC_0_7 ((const struct StelADCInput){ADC0, WNTR_PORT_A, 7, ADC_INPUTCTRL_MUXPOS_AIN7})
#define GPIO_14 (WNTR_GPIO_PIN(WNTR_PORT_A, 6))
#define GPIO_14_ADC_0_6 ((const struct StelADCInput){ADC0, WNTR_PORT_A, 6, ADC_INPUTCTRL_MUXPOS_AIN6})
#define GPIO_15 (WNTR_GPIO_PIN(WNTR_PORT_A, 5))
#define GPIO_15_ADC_0_5_DAC_1 ((const struct StelADCInput){ADC0, WNTR_PORT_A, 5, ADC_INPUTCTRL_MUXPOS_AIN5})
#define GPIO_16 (WNTR_GPIO_PIN(WNTR_PORT_A, 4))
#define GPIO_16_ADC_0_4 ((const struct StelADCInput){ADC0, WNTR_PORT_A, 4, ADC_INPUTCTRL_MUXPOS_AIN4})
#define GPIO_17 (WNTR_GPIO_PIN(WNTR_PORT_B, 7))
#define GPIO_17_ADC_1_9 ((const struct StelADCInput){ADC1, WNTR_PORT_B, 7, ADC_INPUTCTRL_MUXPOS_AIN9})
#define GPIO_18 (WNTR_GPIO_PIN(WNTR_PORT_B, 6))
#define GPIO_18_ADC_1_8 ((const struct StelADCInput){ADC1, WNTR_PORT_B, 8, ADC_INPUTCTRL_MUXPOS_AIN8})
#define GPIO_19 (WNTR_GPIO_PIN(WNTR_PORT_A, 2))
#define GPIO_19_ADC_0_0 ((const struct StelADCInput){ADC0, WNTR_PORT_A, 2, ADC_INPUTCTRL_MUXPOS_AIN0})
#define GPIO_20 (WNTR_GPIO_PIN(WNTR_PORT_B, 1))
#define GPIO_20_ADC_0_13 ((const struct StelADCInput){ADC0, WNTR_PORT_B, 1, ADC_INPUTCTRL_MUXPOS_AIN13})
#define GPIO_21 (WNTR_GPIO_PIN(WNTR_PORT_B, 0))
#define GPIO_21_ADC_0_12 ((const struct StelADCInput){ADC0, WNTR_PORT_B, 0, ADC_INPUTCTRL_MUXPOS_AIN12})
#define GPIO_22 (WNTR_GPIO_PIN(WNTR_PORT_B, 31))
#define GPIO_23 (WNTR_GPIO_PIN(WNTR_PORT_B, 30))
#define GPIO_23_LED (WNTR_GPIO_PIN(WNTR_PORT_B, 30))

/*
    Array of all GPIO pin defs above (not including analog aliases)
*/
static const struct WntrGPIOPin GPIO[] = {
    GPIO_1,  GPIO_2,  GPIO_3,  GPIO_4,  GPIO_5,  GPIO_6,  GPIO_7,  GPIO_8,  GPIO_9,  GPIO_10, GPIO_11, GPIO_12,
    GPIO_13, GPIO_14, GPIO_15, GPIO_16, GPIO_17, GPIO_18, GPIO_19, GPIO_20, GPIO_21, GPIO_22, GPIO_23,
};

/*
    Pins specifically for the multiplexers
*/

#define GPIO_DAC_MUX_A0 (WNTR_GPIO_PIN(WNTR_PORT_B, 16))
#define GPIO_DAC_MUX_A1 (WNTR_GPIO_PIN(WNTR_PORT_B, 17))
#define GPIO_ADC_MUX_A0 (WNTR_GPIO_PIN(WNTR_PORT_B, 2))
#define GPIO_ADC_MUX_A1 (WNTR_GPIO_PIN(WNTR_PORT_B, 3))
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

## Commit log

2021-09-10 Initial commit; unfinished, just saving some stuff before making some big design changes
    [AnalogInBuffers.sch, AnalogOutBuffers.sch, CODEC.sch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]
2021-09-21 Finish up first plausible version
    [AnalogInBuffers.sch, AnalogOutBuffers.sch, mcu.sch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]
2021-09-28 Fix launch stuff and dotstar pin assignments
    [stel_dotstar.c]
2021-09-28 Add ADC to stel_config.h
2021-09-28 Basic ADC functionality
2021-10-03 Update dac driver with notes about hardware issues
2021-10-03 Update config with proper ADC inputs and SPI configuration
2021-10-03 Sercom SPI now takes a const struct pointer
2021-10-03 Make AD5685 driver use passed-in SPI instance
2021-10-03 Add driver for adg1414
2021-10-03 Make note that I forgot to wire up CS for the switches
    [testkit.sch]
2021-10-05 Screaming into the void
    [AnalogInBuffers.sch, AnalogOutBuffers.sch, CODEC.sch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]
2021-10-08 Add a bunch of breakout boards
    [12_bit_analog_out.kicad_pcb, 12_bit_analog_out.sch, 16_bit_analog_out.kicad_pcb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]
2021-10-20 Fix labels on analog in buffers
    [analog_in_buffers.kicad_pcb]
2021-10-26 Add note about range resistors
    [12_bit_analog_out.sch]
2021-10-26 Add pull-ups
    [mux.kicad_pcb, mux.sch]
2021-10-26 Re-do the motherboard
    [AnalogInBuffers.sch, AnalogOutBuffers.sch, DAC.sch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]
2021-11-12 Fix issues found in hardware v1
    [AnalogInBuffers.sch, AnalogOutBuffers.sch, DAC.sch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]
2021-11-12 Remove ADG1414 drivers
2021-11-12 Switch 120MHz clock to reference the 1MHz clock instead of the 32kHz clock
2021-11-12 Update DAC driver to use external analog reference
2021-11-12 Set CS pin to output in AD5685 driver
2021-11-14 Add debug print for sysex 0x07
2021-11-15 Move breakouts into their own folder
    [12_bit_analog_out.kicad_pcb, 12_bit_analog_out.sch, 16_bit_analog_out.kicad_pcb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]
2021-11-15 Rename Testkit board to Hubble
    [AnalogInBuffers.sch, AnalogOutBuffers.sch, DAC.sch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]
2021-11-16 Mark device as self-powered
2021-11-17 Add basic DAC calibration
2021-11-18 Fixup some stuff on the motherboard
    [AnalogInBuffers.sch, AnalogOutBuffers.sch, DAC.sch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]
2021-11-18 Add basic load/save calibration table
2021-11-18 Add missing print to save_calibration_table
    [main.c]
2021-11-19 Finish up VoltageCalibrationTable loading & saving
2021-11-20 More updates to the board design
    - Added polyfuses for downstream power
    - Added breakout header for external, panel-mounted USB port
    - Added I/O breakout for the switches and buttons on the front control panel
    - Made the MCU footprint a hybrid QFP/QFN footprint
    - Add a nice illustration to the board backside
    [AnalogInBuffers.sch, AnalogOutBuffers.sch, CODEC.sch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]
2021-11-20 wntr_debug: Use decimal for the size of the memory being printed
2021-11-20 Use decimal when printing the length of a calibration table
2021-11-20 - Swap channel and mux argument order for sysex commands - Add command for enabling/disabling calibration tables - Extend the length of the DAC calibration table to 16 entries
    [main.c]
2021-11-20 Refilled zones
    [hubble.kicad_pcb]
2021-11-22 Fixup some 3dmodel stuff
    [hubble.kicad_pcb]
2021-11-22 Add IO lens
    [io-lens.pcb.kicad_pcb, io-lens.pcb.sch]
2021-11-29 Add calibration tables for all four DACs
2021-12-08 Add mechanical designs
    [rail-holder.scad, top-plate-to-rail-coupler.scad]
2021-12-08 Add ADC calibration tables
2021-12-08 Add basic scripts for calibrating the ADC & DAC
2021-12-12 Add circuitpython code for the front panel
2021-12-18 python library: add formatting and linting
    [.isort.cfg]
2022-01-01 Update front and back laser cutter templates
2022-01-01 Update design files to KiCAD 6
    [AnalogInBuffers.kicad_sch, AnalogInBuffers.sch, AnalogOutBuffers.kicad_sch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]
2022-01-03 Update mechanical design files
    [angle-bracket.amf, foot.amf, hinge.3mf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]
2023-06-29 fixup DigitalIO.device, change MIDI_PORT_NAME for Pico
    [frontpanel.py, hubble.py]
2023-11-08 Fix some minor issues with the Python library
    [hubble.py]
2023-12-30 Initial stab at hardware revision
    [AnalogInBuffers.kicad_sch, AnalogOutBuffers.kicad_sch, DAC.kicad_sch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]
2024-02-02 Change pin assignments
2024-02-02 Update dostars to use SERCOM SPI
2024-02-02 Cleanup ADC pin defs
2024-02-02 Factor out calibration tables
2024-02-02 Update resistor values in Vout DAC buffers
    [analog-ins-low-voltage.kicad_sch, analog-ins.kicad_sch, analog-outs-low-voltage.kicad_sch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]
2024-02-02 Get ADC working

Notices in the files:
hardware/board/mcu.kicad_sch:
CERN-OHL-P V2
